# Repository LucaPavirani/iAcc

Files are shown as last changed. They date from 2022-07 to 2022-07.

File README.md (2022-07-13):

# Electronic Technologies and Biosensors Laboratory

## Academic Year 2021/2022 - II Semester

## Final Project - Project 4 - Respiratory/Heart Rate Monitor

## Objective

In this project, the aim was to develop a simple **Respiratory/Heart Rate Monitor** based on the PSoC and a 3-axis accelerometer LIS3DH. The device implements an algorithm for respiratory and heart rate computation, and then it allows data visualization on a custom GUI. PSOC and PC communication relies on a HC-05 BT Module either to make the device wearable and to reduce the cable bulkyness.
The PSoC communicates with the LIS3DH thanks to I2C communication, to acquire data at the best full-scale range possible, which has been set to $\pm 2G$, and with sampling frequency of 50 Hz.  
Finally, the whole PCB is powered thanks to a 9V battery, which allows the device to be portable and light. 

In the following image, the device is shown: 

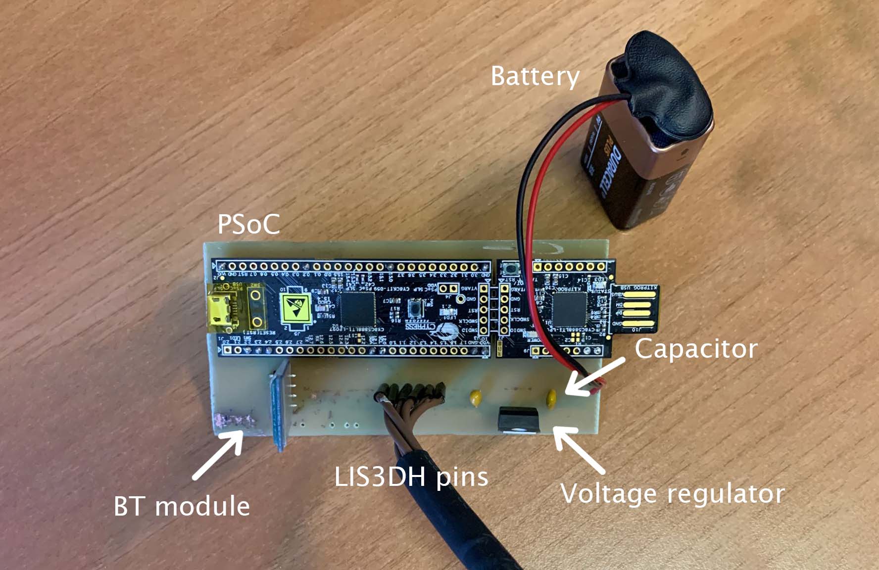
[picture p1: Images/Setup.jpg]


## Repository structure

### Design files

This folder contains all the projects used to model and 3D print the case and the chest mount for the sensor, along with the Eagle files, used to design the PCB. 

### Documentation

This folder contains the literature analysed during the development of the project, while the *Datasheets* folder contains all the datasheets for the components with some other useful files. 

### GUI

The GUI folder contains all the files necessary to run the graphical interface, which is the following:

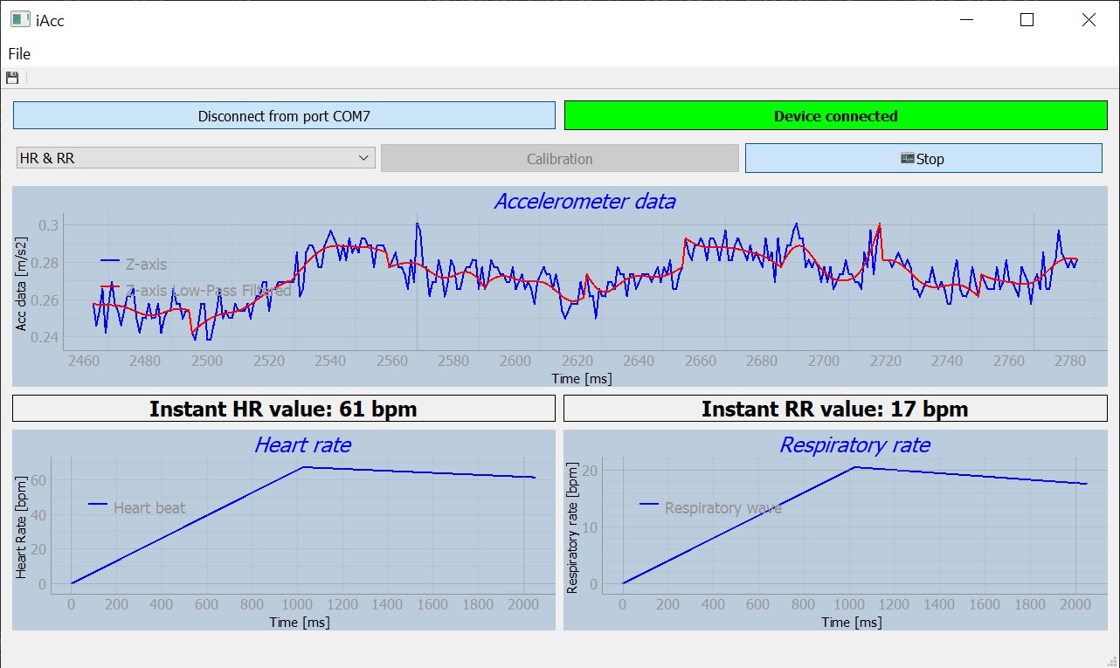
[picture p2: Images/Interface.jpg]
interface


The *device search* button enables the automatic scan of all the serial ports, looking for the device. As soon as it finds it, the connection is established and the box on the right becomes green, confirming the operation. The *combobox* allows to choose to read both HR and RR or only one of them. Calibration must be performed the first time that the device is worn, so that the algorithm computes the proper threshold to detect the rates. Once calibration is over (1 min approx.), the algorithm starts to accumulate data and to calculate the peaks from the signal, in order to compute RR and HR.

The *file* button allows to export the data in a `.csv` file. This operation will be automatically performed if the device is suddenly disconnected, so that the data is not lost. 

Heart Rate and Respiratory Rate are computed on non overlapping recording windows of 30s. Raw data are filtered and analysed in two different way for the computation of the rates. 

### Heart Rate computation

First, the absolute value of recorded data is filtered by a butter bandpass filter of the 4th order with frequency range in [1 ,5]Hz. The resulting signal is then smoothed first by a Savitzky-Golay filter of the 3rd order with window length of 15 samples and then by a moving average. These steps provide a resulting waveform that crearly shows the heart beats while being quite robust against noise.  
The next step provides the threshold as the 80% of the average of the data. The algorithm looks for the peaks above the calculated threshold that are at least 25 samples apart, that correspond to 0.5s approx.  
Finally, the Heart Rate is computed as the fraction between the number of peaks in the recorded window and the length of the window in seconds. This value is updated every 30s approx.

### Respiratory Rate computation

The computation of the Respiratory Rate requires different filtering of the signal.  
First, recorded data go through a butter lowpass filter of the 5th orded with cutoff frequency of 3Hz. This filtered signal is then smoothed by a Savitzky-Golay filter with a window of 31 samples and 3rd order. The threshold is calculated in the same way as in the HR computation, but the peaks are searched every 50 samples. 
The Respiratory Rate is calculated in the same way as the Heart Rate.

### Images

Images used for this `readme` file.

### PSoC

The *PSoC Code* folder contains all the files used to program the PSoC: in particular, all the functions and variables have been reordered in the proper file, allowing to increase the main.c file readibility.  
This code basically sets the proper configuration for the accelerometer registers at startup, making it ready for the data acquisition. All the different phases are managed thanks to a UART, that enables the different operations, according to the signals that come from the GUI. So, at the beginning the accelerometer is set and ready, once the PSoC receives the *start* signal from the GUI it begins to acquire data and to transmit them.  

Regarding the data acquisition, as previously mentioned the accelerometer has been set to a sampling frequency of 50 Hz, according to the Shannon's theorem and to the literature. In addition to that, the accelerometer operates in **FIFO mode**, so it accumulates all the samplings in the FIFO register (which contains up to 32 samples) and then it stops getting new data until the register has been emptied, allowing to reduce the computational load on the CPU and so the battery consumption, with respect to **bypass** mode, that sends the data in a continuous stream.  
In order to read the FIFO register, the PSoC checks regularly the value of the *overrun bit*, that becomes 1 once the FIFO register is full and returns to 0 when it has been entirely read.  
Once the `ovrn bit` changes to one, the register is entirely read, storing the data in the respective axis array. Then, the data is packed in one single array and sent via UART.

*Further implementation details can be found in each file.*

## Complete hardware list

- 1 PSoC CY8CKIT-059 
- 1 LIS3DH accelerometer
- 1 HC05 Bluetooth module
- 1 9V battery
- 1 9V to 5V voltage regulator 
- 6 cables for the accelerometer-PSoC communication

## How to wear the device

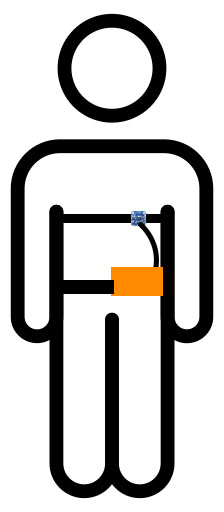
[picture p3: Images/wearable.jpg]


The 3D files for the case and the support can be found in the Design folder.

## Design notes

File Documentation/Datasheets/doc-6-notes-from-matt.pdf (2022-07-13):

# Porting the Arduino Library to the Cypress PSoC in PSoC Creator

Matt Durak

November 11, 2011

Design Team 1

### Abstract

Arduino, the open-source electronic platform is a useful tool to hobbyists in building embedded systems. It provides an easy to use library which includes components to work with an Ethernet board, called the Ethernet shield. PSoC is a programmable system-on-chip made by Cypress Semiconductor. It is a very flexible platform which includes an ARM Cortex M3 processor. This application note includes the steps necessary to port parts of the Arduino library to the PSoC in order to use Arduino software and hardware, known as shields, with the PSoC. The note will cover many issues which must be overcome in porting this software.

### Keywords

PSoC, Arduino, C++, C, Library, Software, Porting, PSoC Creator, Ethernet shield

### Introduction

### Arduino Library

The Arduino is an open-source electronics hardware platform that is designed primarily for students and hobbyists (1). Arduino provides the schematics to build the hardware, as well as kits which can be pre-assembled or just include the parts. This application note will focus on the software for Arduino. Arduino has its own open-source development environment based on Wiring, a platform for programming electronics (2). The software library used by Arduino is written in C++ and is also open-source and freely available (3).

This library is composed of a low layer which communicates directly with hardware registers and provides an abstraction for programmers to set whether a pin is an input or an output and to read and write to those pins. This low layer also handles the other hardware components on the Arduino, such as memory access, timers, pulse width modulators, and several forms of communication. The library also provides higher-level abstractions on top of this in order to make development easier.

The library contains sub-libraries for several Arduino daughterboards, which are called shields. This note will focus on the Ethernet shield as an example, although the note should be applicable to most components of the library. The Ethernet library itself also has a layer which defines the low level registers to communicate with over serial peripheral interface (SPI), as well as high level abstractions which make application code easier to write (4). The Ethernet library uses a separate SPI library component to handle the communication. This library provides an abstract interface to transmit bytes of data. It wraps the actual low level hardware communication in its implementation.

### PSoC Development

The Cypress Programmable System-on-Chip (PSoC), is a configurable piece of hardware which contains a number of programmable virtual components in order to implement a wide range of hardware features. This application note will focus on the PSoC 5, the latest family of PSoC. This version of the board contains an ARM Cortex M3 processor (5).

The development environment used by the PSoC is called PSoC Creator. This software is a full development environment for the PSoC. It contains a schematic layout tool in order to configure the programmable virtual hardware components. It also has a full C language IDE for developing code to run on the PSoC processor (6). This application note will focus on the programming side of PSoC Creator.

### Objective

The objective of this application note is to provide the steps necessary to take the Arduino software libraries, and compile them for the PSoC. This would allow a developer using a PSoC to run Arduino code and to possibly interface with an Arduino shield. The objective is not to show how to actually interface the PSoC hardware with an Arduino shield or to use the schematic layout tool in PSoC Creator. This application note assumes that the reader has acquired the latest development version of Arduino, found on Github (7).

### Issues

There are several issues to be aware of when porting code from one platform to another. The primary concerns in this case are the programming language, the standard libraries used by the code, and the implementation of the low-level details.

The issue with the programming language is mostly an minor incompatibility when using PSoC Creator. The Arduino libraries are primarily written in C++, although a few files are written in C. The PSoC Creator environment only officially supports C. However, PSoC Creator ships with the complete GNU Compiler Collection (GCC), which includes compilers for both C and C++. With a few minor modifications, PSoC Creator can compile C++ code. Another issue is the use of C++ in an embedded environment with very limited memory. C++ uses many advanced features such as polymorphism and virtual methods, templates, and run time type information which can add code bloat if used improperly (8). Fortunately, the standard Arduino board has a flash memory size of 32 KB, which is the same as the simplest PSoC 5 board. This means that the Arduino library has already been optimized to work with a similar memory constraint.

The next issue with the Arduino library code, is that the development library used by Arduino for its AVR ATMega processor uses standard AVR libraries with GCC. The PSoC uses the same version of GCC for embedded development; however it does not contain the AVR library used by Arduino. This requires some modification of the code to use the standard libraries available to PSoC.

Finally, the primary issue which will be addressed in this application note lies in the actual hardware implementations and low-level details of the Arduino library. This part of the code is very specific to the Arduino platform. The implementations will need to be re-written in order to make the library work on the PSoC platform.

### Steps

### Importing Arduino Sources

The process of porting the Arduino code begins with creating a new project in PSoC Creator. Next, it is necessary to create the digital and analog pins as well as any hardware components such as SPI and UART which will be used by the Arduino code. That process should be completed separately. The remaining steps assume that the PSoC Creator project contains a project with the schematic components necessary to emulate an Arduino board.

First, the following sources from the Arduino folder /hardware/cores/arduino/ must be added to the project: Arduino.h, Client.h, IPAddress.cpp, IPAddress.h, Print.cpp, Print.h, Printable.h, Server.h, Stream.cpp, Stream.h, Udp.h, WMath.cpp, binary.h, and new.cpp. It is recommended to add these to a new folder within the PSoC project in order to keep them separated from application code. Next, all files within the directory /libraries/Ethernet/, /libraries/Ethernet/utility/, and /libraries/SPI/ must be added to the project.

At this point, the project will probably build. This is because PSoC Creator does not compile files ending with the “.cpp” file extension. Fixing this requires manually modifying the “.cyprj” file. Open this file and find every “.cpp” file with a line like the following in Figure 1 and change the build action from “NONE” to “C_FILE” as in Figure 2. After repeating this for every C++ source file, save the file and PSoC Creator should reload the file. At this point, the files will all be built, but the compilation will fail.

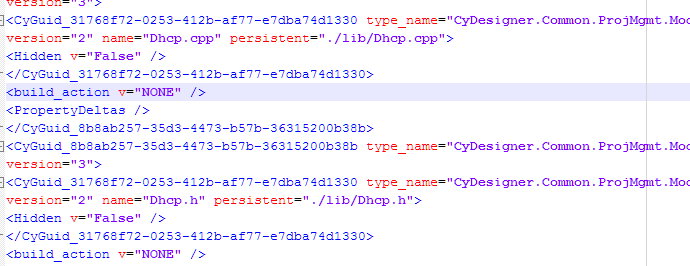
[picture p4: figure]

Figure 1 Project file before modification

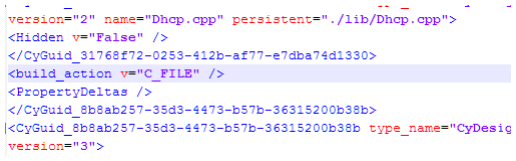
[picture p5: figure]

Figure 2 Project file after modification

### Fixes to get C++ Working

Now that C++ files can be built by PSoC Creator, some changes need to be made to get the project to compile. The first change is to modify the build settings of the project under the “Compiler” section and “Command Line” subsection. That command should include “-I./lib” where “lib” is the folder name where the Arduino sources are located. The command must also include “-fno-rtti” in order to disable run time type information in C++. These two command switches must both be added to make the library work.

Some of the other idiosyncrasies with using C++ are handled nicely by the Arduino library. Take a look at the file New.cpp to see some of the implementation used in order to get C++ working on an embedded system (9). This file is required to get the library to compile and link in PSoC Creator.

At this point, the remaining issues are due to including files that do not exist, using Arduino implementations, and some misnamed functions. However, one final item to note is that when working with C++ and including a C header, it is important to include the code in Listing 1 below. Without the ‘extern “C”’, the code will compile, but it will not link due to C++ name mangling (10). It is important to include this section of code whenever C header files are needed.

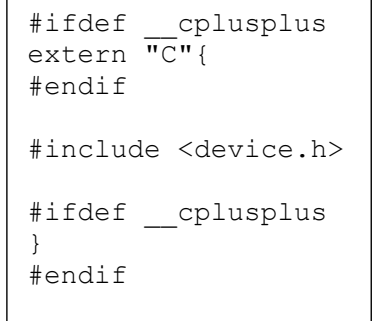
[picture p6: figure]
#ifdef __cplusplus extern "C"{ #endif; #include <device.h>; #ifdef __cplusplus } #endif

Listing 1 Including C headers in C++

### Getting the Library to Compile

The first step to getting the library to compile is to trim out any missing headers and to remove any Arduino specific implementations. The project already only includes a small subset of the entire library, but this next step will polish those sources to get them to work.

All files should have any reference to “AVR” includes removed (Listing 2). This is the standard library used by the AVR ATMega and it is not available for PSoC. The Arduino.h file has these include statements which should be removed. Likewise, any conditional statements using AVR, such as that in Listing 3, should be removed so that only the “else” portion remains.

The following functions in Arduino.h should be removed: init, pinMode, digitalWrite, digitalRead, analogRead, analogReference, analogWrite, micros, delay, delayMicroseconds, pulseIn, shiftOut, shiftIn, attachInterrupt, detachInterrupt, setup, loop, makeWord, tone, and noTone. The functions marked extern should also be removed. The “defines” starting at analogInPinToBit and continuing through TIMER5C should all be removed. Finally, the “includes” for WCharacter.h, WString.h, HardwareSerial.h, and pins_arduino.h should be removed. Within the extern “C” section, an “include” to CyLib.h must be added. This will provide useful functions which were removed from Arduino.h The final source code is included in the appendix.

Listing 2 Example AVR includes to remove

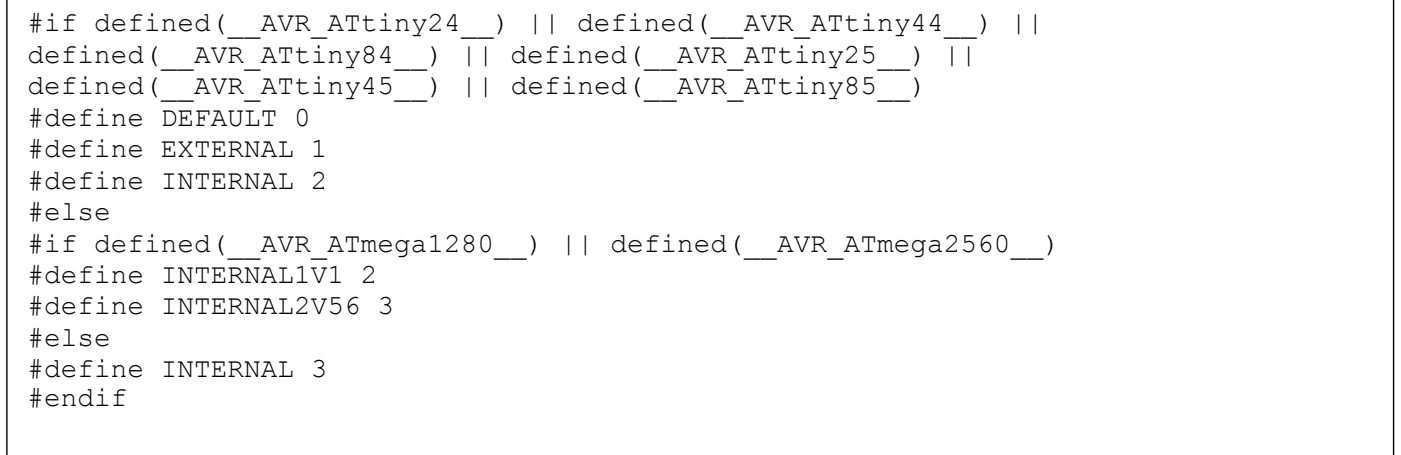
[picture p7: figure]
#define DEFAULT 0 #define EXTERNAL 1 #define INTERNAL 2 #else; #define INTERNAL1V1 2 #define INTERNAL2V56 3 #else #define INTERNAL 3 #endif

Listing 3 Example AVR conditional statements

The next file to modify is Print.h and Print.cpp. Each of these files must be modified to remove the “includes” to WString.h and instead include string.h. All methods that take a “String” or a “__FlashStringHelper” should be removed (Listing 4). These are simply function overloads and it is much easier to not include WString.h. The classes will still work with char* arrays.

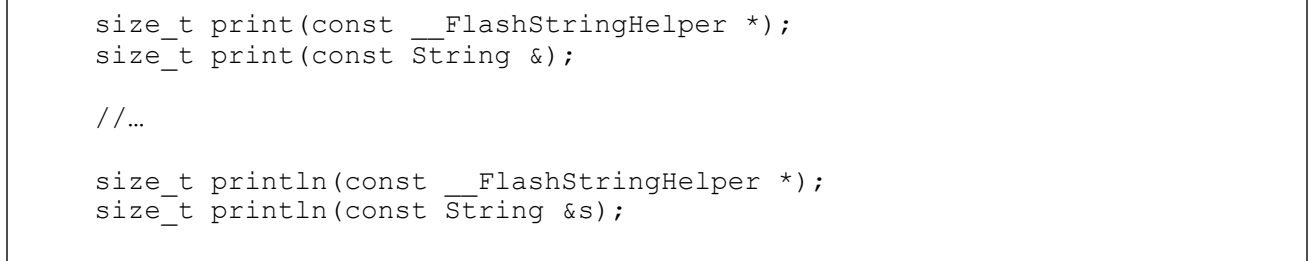
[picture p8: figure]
size_t print(const String &);; size_t println(const String &s);

Listing 4 Functions to remove

The next file to modify is WMath.cpp. This file must have an “include” to Arduino.h added. It must also change “srandom” and “random” to the standard “srand” and “rand” function calls. Finally, this is a good place to implement the “millis()” function. This function is used in Arduino to report the number of milliseconds which have elapsed since the device was powered on. It can be implemented using a counter in PSoC, but that is left to the reader to implement. This finishes the main parts of the Arduino library; next the Ethernet library must be fixed.

One change to make throughout several files here and any others added later, is to change all occurrences of “delay()” to “CyDelay()”. This will be a simple find and replace operation, as the “delay()” function is declared in Arduino.h and now Arduino.h includes CyLib.h which declares “CyDelay()”. This must be fixed in Dhcp.cpp, EthernetClient.cpp, Dns.cpp, and w5100.h.

It should be noted that there are two util.h files. These files should be merged from the main one in hardware to include the one found in the Ethernet library. The Ethernet library version of util.h defines the functions htonl, htons, ntohl, and ntohs in order to convert numbers from host to network endians

#if defined(__AVR_ATtiny24__) || defined(__AVR_ATtiny44__) || defined(__AVR_ATtiny84__) || defined(__AVR_ATtiny25__) || defined(__AVR_ATtiny45__) || defined(__AVR_ATtiny85__)

#if defined(__AVR_ATmega1280__) || defined(__AVR_ATmega2560__)

size_t print(const __FlashStringHelper *);

size_t println(const __FlashStringHelper *);

(which define the order of the bits in a number (11)). The merged version of util.h can be found in the appendix.

The final part of the Ethernet library to fix is the w5100.cpp and w5100.h. The w5100.h file must remove references to the avr headers and add includes to cytypes.h, util.h, and the digital pin used for the Ethernet slave select. The methods initSS, setSS, and resetSS must be changed in order to properly set the SPI slave select pin on the PSoC. The new implementation will not need to initialize the slave select, but it will need to write a “0” to the pin in setSS and write a “1” in resetSS. This code is shown in Listing 5 below. The w5100.cpp file must change delay to “CyDelay” as well as include CyLib.h for this function. There is also a required change in the function “void W5100Class::read_data(SOCKET s, volatile uint8_t *src, volatile uint8_t *dst, uint16_t len)”. There is a compiler error, but the changed code in Listing 6 below will fix this.

Listing 5 The slave select code

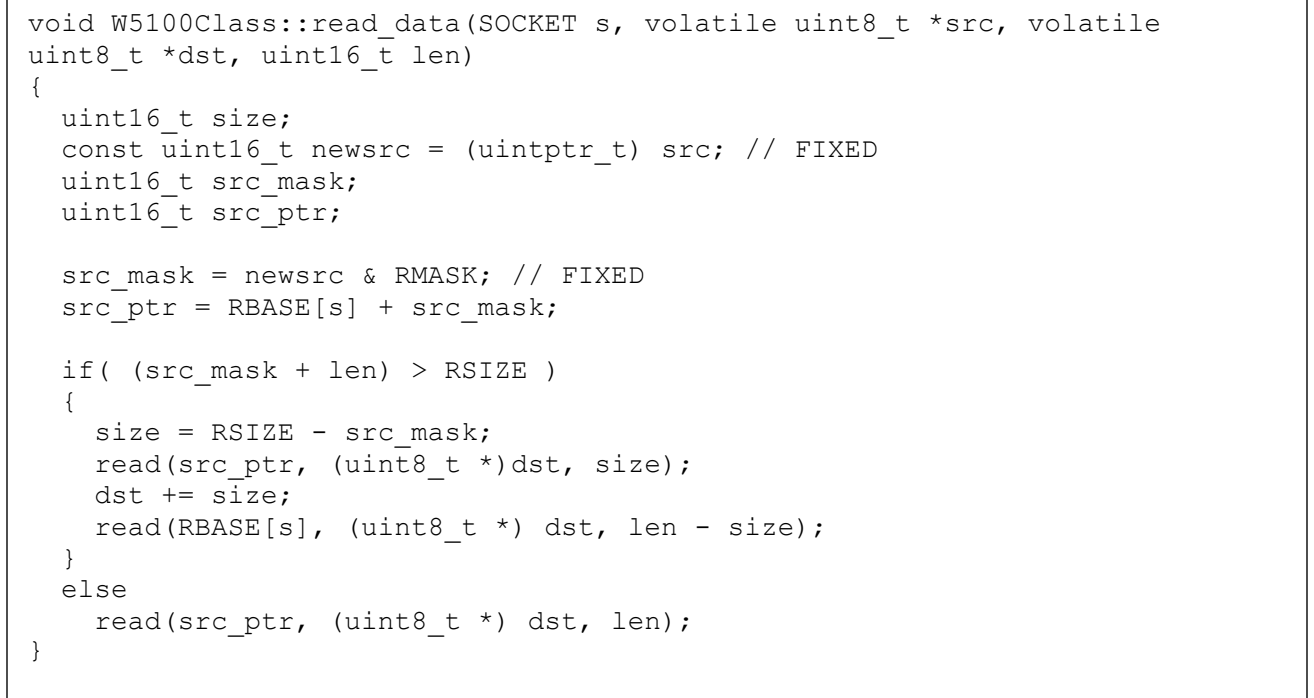
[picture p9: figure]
uint8_t *dst, uint16_t len) {; uint16_t size;; uint16_t src_mask; uint16_t src_ptr;; src_mask = newsrc & RMASK; // FIXED; src_ptr = RBASE[s] + src_mask;; if( (src_mask + len) > RSIZE ) {; size = RSIZE - src_mask; read(src_ptr, (uint8_t *)dst, size); dst += size;; } else read(src_ptr, (uint8_t *) dst, len);

Listing 6 Fixing a compiler error

The final library component to fix is the SPI. The file SPI.cpp requires major changes to the implementation. First the “include” to pins_arduino.h is removed. Next, all function implementation bodies may be removed. The only useful methods are “begin” and “end”. The body for begin should simply call “SPIM_1_Start();” and the body for end should call “SPIM_1_Stop();”. The other functions are configurations of SPI that must be made in the schematic layout mode. They are not necessary for the

inline static void setSS() | { D10_Write(0); /*PORTB &= ~_BV(2);*/ };
inline static void resetSS() | { D10_Write(1); /*PORTB |= | _BV(2);*/ };

void W5100Class::read_data(SOCKET s, volatile uint8_t *src, volatile

const uint16_t newsrc = (uintptr_t) src; // FIXED

read(RBASE[s], (uint8_t *) dst, len - size);

Ethernet library. The file SPI.h must remove the “include” to the avr header and add an “include” to the automatically generated SPI master header (SPIM_1.h by default). In this file, the bodies of attachInterrupt and detachInterrupt can be commented out temporarily. They are not used in the Ethernet code and can be implemented at a later point when they are needed. The most important function is transfer. This function handles actual SPI communication. The body of the function should be replaced with that in Listing 7. This uses the PSoC implementation of SPI. This is the final and most important implementation change to make.

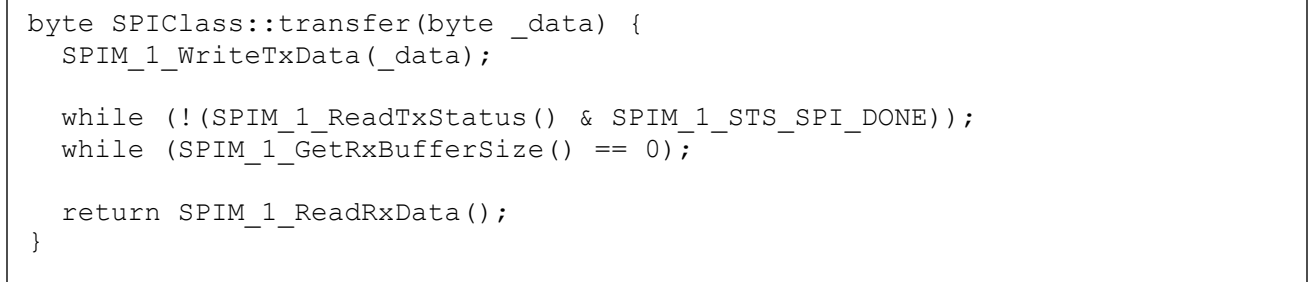
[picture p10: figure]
byte SPIClass::transfer(byte _data) { SPIM_1_WriteTxData(_data);; while (SPIM_1_GetRxBufferSize() == 0);; return SPIM_1_ReadRxData();

Listing 7 The SPI transfer method

### Results

After following the steps of the application note, and creating the proper virtual components in the schematic layout tool, the Arduino library can be built and programmed onto the PSoC. This is a subset of the library including the base components and the Ethernet and SPI libraries. Code that worked on Arduino can be copied into PSoC Creator and compiled to run on the PSoC with very minor modification. After building the hardware to connect the PSoC to an Arduino Ethernet shield, the Arduino Ethernet demos can be run on the PSoC with minor modification.

### Conclusions

Porting code from one embedded system to another can be a challenging task. There are many small implementation details which need to be considered. Likewise, it can be tricky to get C++ code working in an embedded environment which expects C code. However, the end result of this port which leaves the abstract interface intact is that code from one platform can be ported to the other platform for free. Porting the library is an investment which will make future work much easier.

### References

1. Arduino Team. Arduino - Homepage. Arduino. [Online] September 24, 2011. [Cited: November 9, 2011.] http://www.arduino.cc/.
2. Wiring. About Wiring. Wiring. [Online] November 9, 2011. [Cited: November 9, 2011.] http://wiring.org.co/about.html.

while (!(SPIM_1_ReadTxStatus() & SPIM_1_STS_SPI_DONE));

3. Mellis, David A. Introduction. Arduino. [Online] December 23, 2009. [Cited: November 9, 2011.] http://arduino.cc/en/Guide/Introduction.
4. —. Arduino. Ethernet. [Online] February 10, 2009. [Cited: November 9, 2011.] http://arduino.cc/en/Reference/Ethernet.
5. Cypress Semiconductor. PSoC 5 Introduction. Cypress. [Online] November 9, 2011. [Cited: November 9, 2011.] http://www.cypress.com/?id=2233&rID=37591.
6. —. PSoC Creator Overview. Cypress. [Online] November 9, 2011. [Cited: November 9, 2011.] http://www.cypress.com/?id=2494.
7. Arduino. Arduino. Github. [Online] November 9, 2011. [Cited: November 9, 2011.] https://github.com/arduino/Arduino.
8. Neundorf, Alexander. C vs. C++ for embedded development. KDE Blog. [Online] June 7, 2005. [Cited: November 9, 2011.] http://blogs.kde.org/node/1138.
9. Zed, Rob. GCC C++ Link problems on small embedded target. Zedcode. [Online] February 17, 2007. [Cited: November 9, 2011.] http://zedcode.blogspot.com/2007/02/gcc-c-link-problems-on-small-embedded.html.
10. Cline, Marshall. Why is the linker giving errors for C/C++ functions being called from C++/C functions? C++ FAQ Lite. [Online] July 28, 2011. [Cited: November 9, 2011.] http://www.parashift.com/c++-faq-lite/mixing-c-and-cpp.html#faq-32.7.
11. Hall, Brian. Beej's Guide to Network Programming. Beej.us. [Online] September 8, 2009. [Cited: November 9, 2011.] http://beej.us/guide/bgnet/output/html/multipage/htonsman.html.

### Appendix

### Arduino.h

#ifndef Arduino_h

#define Arduino_h

#include <stdlib.h>

#include <string.h>

#include <math.h>

#include "binary.h"

#ifdef __cplusplus

extern "C"{
#endif

#include <CyLib.h>

#define HIGH 0x1

#define LOW 0x0

#define INPUT 0x0

#define OUTPUT 0x1

#define true 0x1

#define false 0x0

#define PI 3.1415926535897932384626433832795

#define HALF_PI 1.5707963267948966192313216916398 #define TWO_PI 6.283185307179586476925286766559 #define DEG_TO_RAD 0.017453292519943295769236907684886 #define RAD_TO_DEG 57.295779513082320876798154814105

#define SERIAL 0x0

#define DISPLAY 0x1

#define LSBFIRST 0

#define MSBFIRST 1

#define CHANGE 1

#define FALLING 2

#define RISING 3

#define INTERNAL 3

#define DEFAULT 1

#define EXTERNAL 0

// undefine stdlib's abs if encountered #ifdef abs
#undef abs

#endif

#define min(a,b) ((a)<(b)?(a):(b)) #define max(a,b) ((a)>(b)?(a):(b))

#define abs(x) ((x)>0?(x):-(x))

#define constrain(amt,low,high) ((amt)<(low)?(low):((amt)>(high)?(high):(amt)))

#define round(x) | ((x)>=0?(long)((x)+0.5):(long)((x)-0.5))

#define radians(deg) ((deg)*DEG_TO_RAD)

#define degrees(rad) ((rad)*RAD_TO_DEG)

#define sq(x) ((x)*(x))

#define interrupts() sei()

#define noInterrupts() cli()

#define clockCyclesPerMicrosecond() ( F_CPU / 1000000L )

#define clockCyclesToMicroseconds(a) ( ((a) * 1000L) / (F_CPU / 1000L) ) #define microsecondsToClockCycles(a) ( ((a) * (F_CPU / 1000L)) / 1000L )

#define lowByte(w) ((uint8_t) ((w) & 0xff))

#define highByte(w) ((uint8_t) ((w) >> 8))

#define bitRead(value, bit) (((value) >> (bit)) & 0x01)

#define bitSet(value, bit) ((value) |= (1UL << (bit)))

#define bitClear(value, bit) ((value) &= ~(1UL << (bit)))

#define bitWrite(value, bit, bitvalue) (bitvalue ? bitSet(value, bit) : bitClear(value, bit))

typedef unsigned int word;

#define bit(b) (1UL << (b))

typedef uint8_t boolean;
typedef uint8_t byte;

unsigned long millis(void);

#ifdef __cplusplus

} // extern "C"
#endif

#ifdef __cplusplus

// WMath prototypes
long random(long);
long random(long, long);
void randomSeed(unsigned int);
long map(long, long, long, long, long);

#endif

#endif

### Util.h

#ifndef UTIL_INCLUDED

#define UTIL_INCLUDED

#define _BV(bit) (1 << (bit))

#ifdef __cplusplus

extern "C"{
#endif

#include <CyLib.h>

#ifdef __cplusplus

}
#endif

#define htons(x) CYSWAP_ENDIAN16(x) #define ntohs(x) htons(x)

#define htonl(x) CYSWAP_ENDIAN32(x) #define ntohl(x) htonl(x)

#endif

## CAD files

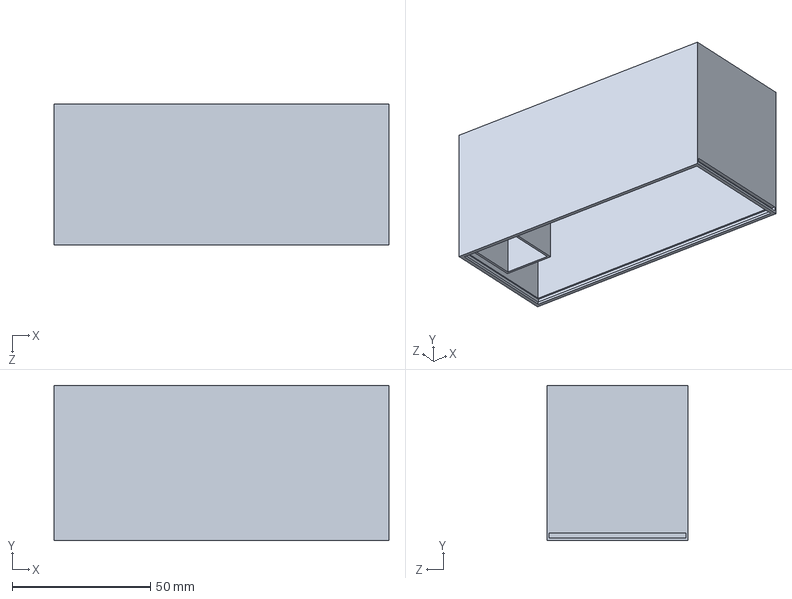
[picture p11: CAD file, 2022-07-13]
Design files/3D printer/case.SLDPRT
121.0 x 56.0 x 51.0 mm

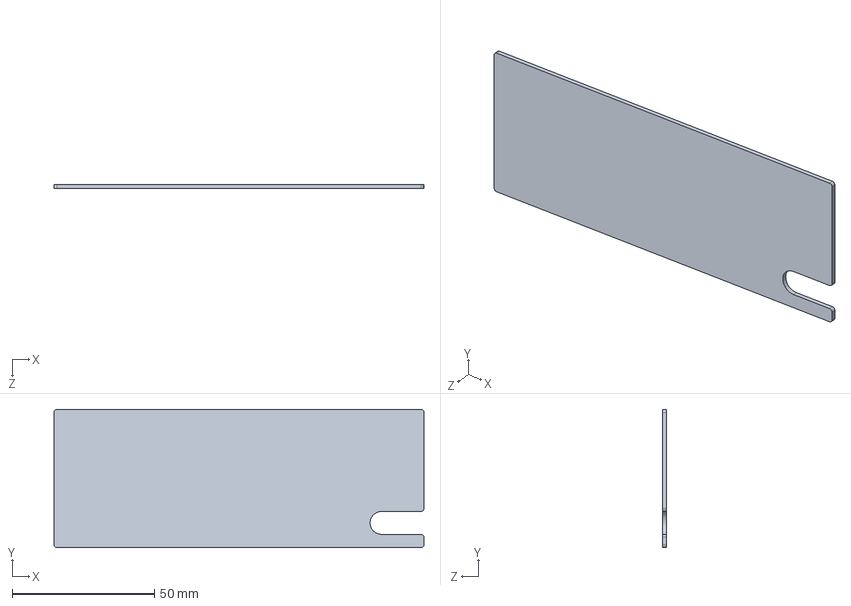
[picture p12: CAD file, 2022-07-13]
Design files/3D printer/supportLid.SLDPRT
130.0 x 48.5 x 1.45 mm

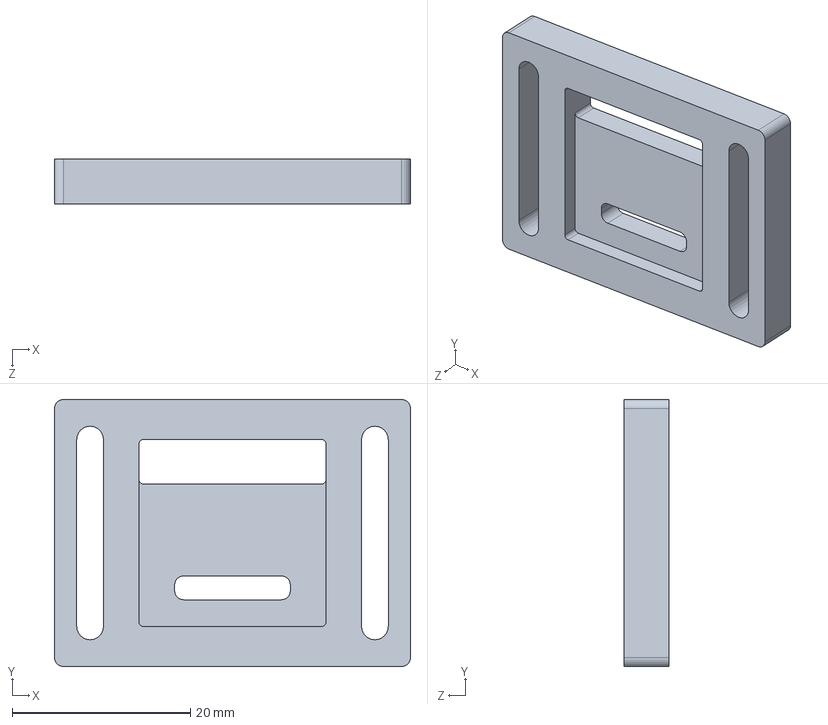
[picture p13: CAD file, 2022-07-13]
Design files/3D printer/accelerometerSupport.SLDPRT
40.0 x 30.0 x 5.00 mm

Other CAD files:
Design files/3D printer/accelerometerSupport.STL
Design files/3D printer/case.STL
Design files/3D printer/supportLid.STL

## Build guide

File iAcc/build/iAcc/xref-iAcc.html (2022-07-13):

# modulegraph cross reference for iAcc.py, pyi_rth_inspect.py, pyi_rth_mplconfig.py, pyi_rth_multiprocessing.py, pyi_rth_pkgres.py, pyi_rth_pkgutil.py, pyi_rth_pyqt5.py, pyi_rth_subprocess.py

iAcc.py Script

imports: PyQt5 • PyQt5.QtCore • PyQt5.QtGui • PyQt5.QtWidgets • _bootlocale • _collections_abc • _weakrefset • abc • codecs • collections • collections.abc • copyreg • encodings • encodings.aliases • encodings.ascii • encodings.base64_codec • encodings.big5 • encodings.big5hkscs • encodings.bz2_codec • encodings.charmap • encodings.cp037 • encodings.cp1006 • encodings.cp1026 • encodings.cp1125 • encodings.cp1140 • encodings.cp1250 • encodings.cp1251 • encodings.cp1252 • encodings.cp1253 • encodings.cp1254 • encodings.cp1255 • encodings.cp1256 • encodings.cp1257 • encodings.cp1258 • encodings.cp273 • encodings.cp424 • encodings.cp437 • encodings.cp500 • encodings.cp65001 • encodings.cp720 • encodings.cp737 • encodings.cp775 • encodings.cp850 • encodings.cp852 • encodings.cp855 • encodings.cp856 • encodings.cp857 • encodings.cp858 • encodings.cp860 • encodings.cp861 • encodings.cp862 • encodings.cp863 • encodings.cp864 • encodings.cp865 • encodings.cp866 • encodings.cp869 • encodings.cp874 • encodings.cp875 • encodings.cp932 • encodings.cp949 • encodings.cp950 • encodings.euc_jis_2004 • encodings.euc_jisx0213 • encodings.euc_jp • encodings.euc_kr • encodings.gb18030 • encodings.gb2312 • encodings.gbk • encodings.hex_codec • encodings.hp_roman8 • encodings.hz • encodings.idna • encodings.iso2022_jp • encodings.iso2022_jp_1 • encodings.iso2022_jp_2 • encodings.iso2022_jp_2004 • encodings.iso2022_jp_3 • encodings.iso2022_jp_ext • encodings.iso2022_kr • encodings.iso8859_1 • encodings.iso8859_10 • encodings.iso8859_11 • encodings.iso8859_13 • encodings.iso8859_14 • encodings.iso8859_15 • encodings.iso8859_16 • encodings.iso8859_2 • encodings.iso8859_3 • encodings.iso8859_4 • encodings.iso8859_5 • encodings.iso8859_6 • encodings.iso8859_7 • encodings.iso8859_8 • encodings.iso8859_9 • encodings.johab • encodings.koi8_r • encodings.koi8_t • encodings.koi8_u • encodings.kz1048 • encodings.latin_1 • encodings.mac_arabic • encodings.mac_centeuro • encodings.mac_croatian • encodings.mac_cyrillic • encodings.mac_farsi • encodings.mac_greek • encodings.mac_iceland • encodings.mac_latin2 • encodings.mac_roman • encodings.mac_romanian • encodings.mac_turkish • encodings.mbcs • encodings.oem • encodings.palmos • encodings.ptcp154 • encodings.punycode • encodings.quopri_codec • encodings.raw_unicode_escape • encodings.rot_13 • encodings.shift_jis • encodings.shift_jis_2004 • encodings.shift_jisx0213 • encodings.tis_620 • encodings.undefined • encodings.unicode_escape • encodings.unicode_internal • encodings.utf_16 • encodings.utf_16_be • encodings.utf_16_le • encodings.utf_32 • encodings.utf_32_be • encodings.utf_32_le • encodings.utf_7 • encodings.utf_8 • encodings.utf_8_sig • encodings.uu_codec • encodings.zlib_codec • enum • functools • heapq • io • keyword • linecache • locale • logging • matplotlib.pyplot • numpy • operator • pandas • pyi_rth_inspect.py • pyi_rth_mplconfig.py • pyi_rth_multiprocessing.py • pyi_rth_pkgres.py • pyi_rth_pkgutil.py • pyi_rth_pyqt5.py • pyi_rth_subprocess.py • pyqtgraph • re • reprlib • scipy.signal • serial • serial.tools.list_ports • setuptools • sre_compile • sre_constants • sre_parse • struct • sys • telnetlib • time • tokenize • traceback • types • variables • warnings • weakref

pyi_rth_inspect.py Script

imports: inspect • os • sys

imported by: iAcc.py

pyi_rth_mplconfig.py Script

imports: atexit • os • shutil • tempfile

imported by: iAcc.py

pyi_rth_multiprocessing.py Script

imports: multiprocessing • multiprocessing.popen_fork • multiprocessing.popen_spawn_posix • multiprocessing.popen_spawn_win32 • multiprocessing.spawn • os • subprocess • sys

imported by: iAcc.py

pyi_rth_pkgres.py Script

imports: os • pathlib • pkg_resources • pyimod03_importers • sys

imported by: iAcc.py

pyi_rth_pkgutil.py Script

imports: os • pkgutil • pyimod03_importers • sys

imported by: iAcc.py

pyi_rth_pyqt5.py Script

imports: os • sys

imported by: iAcc.py

pyi_rth_subprocess.py Script

imports: io • subprocess • sys

imported by: iAcc.py

'IPython.core' MissingModule

imported by: matplotlib.backend_bases • matplotlib.pyplot • pandas.io.formats.printing

'OpenGL.GL' MissingModule

imported by: pyqtgraph.widgets.RawImageWidget

'PyQt6.QtCore' MissingModule

imported by: pyqtgraph.Qt

'PyQt6.QtGui' MissingModule

imported by: PIL.ImageQt • pyqtgraph.Qt

'PyQt6.QtWidgets' MissingModule

imported by: pyqtgraph.Qt

'PySide2.QtCore' MissingModule

imported by: pyqtgraph.GraphicsScene.exportDialogTemplate_pyside2 • pyqtgraph.Qt • pyqtgraph.examples.VideoTemplate_pyside2 • pyqtgraph.examples.exampleLoaderTemplate_pyside2

'PySide2.QtGui' MissingModule

imported by: PIL.ImageQt • pyqtgraph.GraphicsScene.exportDialogTemplate_pyside2 • pyqtgraph.Qt • pyqtgraph.examples.VideoTemplate_pyside2 • pyqtgraph.examples.exampleLoaderTemplate_pyside2

'PySide2.QtWidgets' MissingModule

imported by: pyqtgraph.GraphicsScene.exportDialogTemplate_pyside2 • pyqtgraph.Qt • pyqtgraph.examples.VideoTemplate_pyside2 • pyqtgraph.examples.exampleLoaderTemplate_pyside2

'PySide6.QtCore' MissingModule

imported by: pyqtgraph.GraphicsScene.exportDialogTemplate_pyside6 • pyqtgraph.Qt • pyqtgraph.canvas.CanvasTemplate_pyside6 • pyqtgraph.canvas.TransformGuiTemplate_pyside6 • pyqtgraph.examples.VideoTemplate_pyside6 • pyqtgraph.examples.exampleLoaderTemplate_pyside6 • pyqtgraph.flowchart.FlowchartCtrlTemplate_pyside6 • pyqtgraph.flowchart.FlowchartTemplate_pyside6 • pyqtgraph.graphicsItems.PlotItem.plotConfigTemplate_pyside6 • pyqtgraph.graphicsItems.ViewBox.axisCtrlTemplate_pyside6 • pyqtgraph.imageview.ImageViewTemplate_pyside6

'PySide6.QtGui' MissingModule

imported by: PIL.ImageQt • pyqtgraph.GraphicsScene.exportDialogTemplate_pyside6 • pyqtgraph.Qt • pyqtgraph.canvas.CanvasTemplate_pyside6 • pyqtgraph.canvas.TransformGuiTemplate_pyside6 • pyqtgraph.examples.VideoTemplate_pyside6 • pyqtgraph.examples.exampleLoaderTemplate_pyside6 • pyqtgraph.flowchart.FlowchartCtrlTemplate_pyside6 • pyqtgraph.flowchart.FlowchartTemplate_pyside6 • pyqtgraph.graphicsItems.PlotItem.plotConfigTemplate_pyside6 • pyqtgraph.graphicsItems.ViewBox.axisCtrlTemplate_pyside6 • pyqtgraph.imageview.ImageViewTemplate_pyside6

'PySide6.QtWidgets' MissingModule

imported by: pyqtgraph.GraphicsScene.exportDialogTemplate_pyside6 • pyqtgraph.Qt • pyqtgraph.canvas.CanvasTemplate_pyside6 • pyqtgraph.canvas.TransformGuiTemplate_pyside6 • pyqtgraph.examples.VideoTemplate_pyside6 • pyqtgraph.examples.exampleLoaderTemplate_pyside6 • pyqtgraph.flowchart.FlowchartCtrlTemplate_pyside6 • pyqtgraph.flowchart.FlowchartTemplate_pyside6 • pyqtgraph.graphicsItems.PlotItem.plotConfigTemplate_pyside6 • pyqtgraph.graphicsItems.ViewBox.axisCtrlTemplate_pyside6 • pyqtgraph.imageview.ImageViewTemplate_pyside6

'System.IO' MissingModule

imported by: serial.serialcli

'backports.ssl_match_hostname' MissingModule

imported by: setuptools.ssl_support

'com.sun' MissingModule

imported by: pkg_resources._vendor.appdirs

'h5py.highlevel' MissingModule

imported by: pyqtgraph.metaarray.MetaArray

'java.lang' MissingModule

imported by: platform • xml.sax._exceptions

'lxml.etree' MissingModule

imported by: pandas.io.formats.xml • pandas.io.html • pandas.io.xml

'lxml.html' MissingModule

imported by: pandas.io.html

'nose.plugins' MissingModule

imported by: numpy.testing._private.noseclasses • numpy.testing._private.nosetester

'nose.util' MissingModule

imported by: numpy.testing._private.noseclasses

'odf.config' MissingModule

imported by: pandas.io.excel._odswriter

'odf.element' MissingModule

imported by: pandas.io.excel._odfreader

'odf.namespaces' MissingModule

imported by: pandas.io.excel._odfreader

'odf.opendocument' MissingModule

imported by: pandas.io.excel._odfreader • pandas.io.excel._odswriter

'odf.style' MissingModule

imported by: pandas.io.excel._odswriter

'odf.table' MissingModule

imported by: pandas.io.excel._odfreader • pandas.io.excel._odswriter

'odf.text' MissingModule

imported by: pandas.io.excel._odfreader • pandas.io.excel._odswriter

'openpyxl.cell' MissingModule

imported by: pandas.io.excel._openpyxl

'openpyxl.styles' MissingModule

imported by: pandas.io.excel._openpyxl

'openpyxl.workbook' MissingModule

imported by: pandas.io.excel._openpyxl

'org.python' MissingModule

imported by: pickle • setuptools.sandbox • xml.sax

'pkg_resources.extern.pyparsing' MissingModule

imported by: pkg_resources._vendor.packaging.markers • pkg_resources._vendor.packaging.requirements

'pkg_resources.extern.six.moves' MissingModule

imported by: pkg_resources • pkg_resources._vendor.packaging.requirements

'pyarrow.compute' MissingModule

imported by: pandas.core.arrays.string_arrow

'pyarrow.parquet' MissingModule

imported by: pandas.io.parquet

'scikits.umfpack' MissingModule

imported by: scipy.optimize._linprog_ip

'setuptools._vendor.six.moves' MissingModule

imported by: 'setuptools._vendor.six.moves'

'setuptools._vendor.six.moves' AliasNode

imports: 'setuptools._vendor.six.moves' • 'setuptools._vendor.six.moves'.parse • setuptools.extern.six.moves

imported by: setuptools._vendor.packaging.requirements • setuptools.extern.six.moves • setuptools.package_index • setuptools.ssl_support

'setuptools._vendor.six.moves'.parse MissingModule

imported by: 'setuptools._vendor.six.moves' • setuptools._vendor.packaging.requirements

'setuptools.extern.packaging' MissingModule

imported by: setuptools.wheel

'setuptools.extern.packaging.version' MissingModule

imported by: setuptools.config • setuptools.msvc

'setuptools.extern.pyparsing' MissingModule

imported by: setuptools._vendor.packaging.markers • setuptools._vendor.packaging.requirements

'setuptools.extern.six' MissingModule

imported by: setuptools

'sksparse.cholmod' MissingModule

imported by: scipy.optimize._linprog_ip

'sqlalchemy.schema' MissingModule

imported by: pandas.io.sql

'sqlalchemy.types' MissingModule

imported by: pandas.io.sql

'tornado.ioloop' MissingModule

imported by: matplotlib.backends.backend_webagg

'tornado.template' MissingModule

imported by: matplotlib.backends.backend_webagg

'tornado.web' MissingModule

imported by: matplotlib.backends.backend_webagg

'tornado.websocket' MissingModule

imported by: matplotlib.backends.backend_webagg

'win32com.shell' MissingModule

imported by: pkg_resources._vendor.appdirs

AppKit MissingModule

imported by: pandas.io.clipboard

CanvasManager MissingModule

imported by: pyqtgraph.canvas.CanvasTemplate_pyside2

Foundation MissingModule

imported by: pandas.io.clipboard

GraphicsView MissingModule

imported by: pyqtgraph.SRTTransform • pyqtgraph.SRTTransform3D

IPython MissingModule

imported by: matplotlib.backend_bases • matplotlib.pyplot • pandas.io.formats.printing

OpenGL MissingModule

imported by: pyqtgraph.graphicsItems.PlotCurveItem

PIL Package

imports: PIL • PIL.BmpImagePlugin • PIL.FitsImagePlugin • PIL.GifImagePlugin • PIL.GimpGradientFile • PIL.GimpPaletteFile • PIL.Image • PIL.ImageChops • PIL.ImageColor • PIL.ImageFile • PIL.ImageFilter • PIL.ImageMode • PIL.ImageOps • PIL.ImagePalette • PIL.ImageQt • PIL.ImageSequence • PIL.ImageShow • PIL.ImageTk • PIL.JpegImagePlugin • PIL.PaletteFile • PIL.PdfParser • PIL.PngImagePlugin • PIL.PpmImagePlugin • PIL.PyAccess • PIL.TiffImagePlugin • PIL.TiffTags • PIL._imaging • PIL._imagingtk • PIL._version • PIL._webp • PIL.features

imported by: PIL • PIL.BlpImagePlugin • PIL.BmpImagePlugin • PIL.BufrStubImagePlugin • PIL.CurImagePlugin • PIL.DcxImagePlugin • PIL.DdsImagePlugin • PIL.EpsImagePlugin • PIL.FitsImagePlugin • PIL.FitsStubImagePlugin • PIL.FliImagePlugin • PIL.FpxImagePlugin • PIL.FtexImagePlugin • PIL.GbrImagePlugin • PIL.GifImagePlugin • PIL.GimpGradientFile • PIL.GimpPaletteFile • PIL.GribStubImagePlugin • PIL.Hdf5StubImagePlugin • PIL.IcnsImagePlugin • PIL.IcoImagePlugin • PIL.ImImagePlugin • PIL.Image • PIL.ImageChops • PIL.ImageColor • PIL.ImageFile • PIL.ImageFilter • PIL.ImageMode • PIL.ImageOps • PIL.ImagePalette • PIL.ImageQt • PIL.ImageSequence • PIL.ImageShow • PIL.ImageTk • PIL.ImtImagePlugin • PIL.IptcImagePlugin • PIL.Jpeg2KImagePlugin • PIL.JpegImagePlugin • PIL.JpegPresets • PIL.McIdasImagePlugin • PIL.MicImagePlugin • PIL.MpegImagePlugin • PIL.MpoImagePlugin • PIL.MspImagePlugin • PIL.PaletteFile • PIL.PalmImagePlugin • PIL.PcdImagePlugin • PIL.PcxImagePlugin • PIL.PdfImagePlugin • PIL.PdfParser • PIL.PixarImagePlugin • PIL.PngImagePlugin • PIL.PpmImagePlugin • PIL.PsdImagePlugin • PIL.PyAccess • PIL.SgiImagePlugin • PIL.SpiderImagePlugin • PIL.SunImagePlugin • PIL.TgaImagePlugin • PIL.TiffImagePlugin • PIL.TiffTags • PIL.WebPImagePlugin • PIL.WmfImagePlugin • PIL.XVThumbImagePlugin • PIL.XbmImagePlugin • PIL.XpmImagePlugin • PIL._binary • PIL._imaging • PIL._imagingtk • PIL._util • PIL._version • PIL._webp • PIL.features • PyInstaller.building.icon • PyInstaller.building.splash • matplotlib.backends.backend_agg • matplotlib.backends.backend_webagg_core • matplotlib.colors • matplotlib.mathtext

PIL.BlpImagePlugin SourceModule

imports: PIL • PIL.Image • PIL.ImageFile • PIL.JpegImagePlugin • enum • io • os • struct • warnings

imported by: PIL.Image

PIL.BmpImagePlugin SourceModule

imports: PIL • PIL.Image • PIL.ImageFile • PIL.ImagePalette • PIL._binary • os

imported by: PIL • PIL.CurImagePlugin • PIL.IcoImagePlugin • PIL.Image

PIL.BufrStubImagePlugin SourceModule

imports: PIL • PIL.Image • PIL.ImageFile

imported by: PIL.Image

PIL.CurImagePlugin SourceModule

imports: PIL • PIL.BmpImagePlugin • PIL.Image • PIL._binary

imported by: PIL.Image

PIL.DcxImagePlugin SourceModule

imports: PIL • PIL.Image • PIL.PcxImagePlugin • PIL._binary

imported by: PIL.Image

PIL.DdsImagePlugin SourceModule

imports: PIL • PIL.Image • PIL.ImageFile • PIL._binary • io • struct

imported by: PIL.Image

PIL.EpsImagePlugin SourceModule

imports: PIL • PIL.Image • PIL.ImageFile • PIL._binary • io • os • re • shutil • subprocess • sys • tempfile

imported by: PIL.Image

PIL.FitsImagePlugin SourceModule

imports: PIL • PIL.Image • PIL.ImageFile • math

imported by: PIL • PIL.FitsStubImagePlugin • PIL.Image

PIL.FitsStubImagePlugin SourceModule

imports: PIL • PIL.FitsImagePlugin • PIL.Image • PIL.ImageFile • warnings

imported by: PIL.Image

PIL.FliImagePlugin SourceModule

imports: PIL • PIL.Image • PIL.ImageFile • PIL.ImagePalette • PIL._binary

imported by: PIL.Image

PIL.FpxImagePlugin SourceModule

imports: PIL • PIL.Image • PIL.ImageFile • PIL._binary • olefile

imported by: PIL.Image

PIL.FtexImagePlugin SourceModule

imports: PIL • PIL.Image • PIL.ImageFile • enum • io • struct • warnings

imported by: PIL.Image

PIL.GbrImagePlugin SourceModule

imports: PIL • PIL.Image • PIL.ImageFile • PIL._binary

imported by: PIL.Image

PIL.GifImagePlugin SourceModule

imports: PIL • PIL.Image • PIL.ImageChops • PIL.ImageFile • PIL.ImagePalette • PIL.ImageSequence • PIL._binary • copy • enum • itertools • math • os • subprocess

imported by: PIL • PIL.Image

PIL.GimpGradientFile SourceModule

imports: PIL • PIL._binary • math

imported by: PIL • PIL.ImagePalette

PIL.GimpPaletteFile SourceModule

imports: PIL • PIL._binary • re

imported by: PIL • PIL.ImagePalette

PIL.GribStubImagePlugin SourceModule

imports: PIL • PIL.Image • PIL.ImageFile

imported by: PIL.Image

PIL.Hdf5StubImagePlugin SourceModule

imports: PIL • PIL.Image • PIL.ImageFile

imported by: PIL.Image

PIL.IcnsImagePlugin SourceModule

imports: PIL • PIL.Image • PIL.ImageFile • PIL.Jpeg2KImagePlugin • PIL.PngImagePlugin • PIL.features • io • os • struct • sys

imported by: PIL.Image

PIL.IcoImagePlugin SourceModule

imports: PIL • PIL.BmpImagePlugin • PIL.Image • PIL.ImageFile • PIL.PngImagePlugin • PIL._binary • io • math • warnings

imported by: PIL.Image

PIL.ImImagePlugin SourceModule

imports: PIL • PIL.Image • PIL.ImageFile • PIL.ImagePalette • os • re

imported by: PIL.Image

PIL.Image SourceModule

imports: PIL • PIL.BlpImagePlugin • PIL.BmpImagePlugin • PIL.BufrStubImagePlugin • PIL.CurImagePlugin • PIL.DcxImagePlugin • PIL.DdsImagePlugin • PIL.EpsImagePlugin • PIL.FitsImagePlugin • PIL.FitsStubImagePlugin • PIL.FliImagePlugin • PIL.FpxImagePlugin • PIL.FtexImagePlugin • PIL.GbrImagePlugin • PIL.GifImagePlugin • PIL.GribStubImagePlugin • PIL.Hdf5StubImagePlugin • PIL.IcnsImagePlugin • PIL.IcoImagePlugin • PIL.ImImagePlugin • PIL.ImageColor • PIL.ImageFilter • PIL.ImageMode • PIL.ImagePalette • PIL.ImageQt • PIL.ImageShow • PIL.ImtImagePlugin • PIL.IptcImagePlugin • PIL.Jpeg2KImagePlugin • PIL.JpegImagePlugin • PIL.McIdasImagePlugin • PIL.MicImagePlugin • PIL.MpegImagePlugin • PIL.MpoImagePlugin • PIL.MspImagePlugin • PIL.PalmImagePlugin • PIL.PcdImagePlugin • PIL.PcxImagePlugin • PIL.PdfImagePlugin • PIL.PixarImagePlugin • PIL.PngImagePlugin • PIL.PpmImagePlugin • PIL.PsdImagePlugin • PIL.PyAccess • PIL.SgiImagePlugin • PIL.SpiderImagePlugin • PIL.SunImagePlugin • PIL.TgaImagePlugin • PIL.TiffImagePlugin • PIL.TiffTags • PIL.WebPImagePlugin • PIL.WmfImagePlugin • PIL.XVThumbImagePlugin • PIL.XbmImagePlugin • PIL.XpmImagePlugin • PIL._binary • PIL._imaging • PIL._util • atexit • builtins • cffi • collections.abc • defusedxml • enum • io • logging • math • numbers • numpy • os • pathlib • re • struct • sys • tempfile • warnings

imported by: PIL • PIL.BlpImagePlugin • PIL.BmpImagePlugin • PIL.BufrStubImagePlugin • PIL.CurImagePlugin • PIL.DcxImagePlugin • PIL.DdsImagePlugin • PIL.EpsImagePlugin • PIL.FitsImagePlugin • PIL.FitsStubImagePlugin • PIL.FliImagePlugin • PIL.FpxImagePlugin • PIL.FtexImagePlugin • PIL.GbrImagePlugin • PIL.GifImagePlugin • PIL.GribStubImagePlugin • PIL.Hdf5StubImagePlugin • PIL.IcnsImagePlugin • PIL.IcoImagePlugin • PIL.ImImagePlugin • PIL.ImageChops • PIL.ImageColor • PIL.ImageFile • PIL.ImageFilter • PIL.ImageOps • PIL.ImageQt • PIL.ImageShow • PIL.ImageTk • PIL.ImtImagePlugin • PIL.IptcImagePlugin • PIL.Jpeg2KImagePlugin • PIL.JpegImagePlugin • PIL.McIdasImagePlugin • PIL.MicImagePlugin • PIL.MpegImagePlugin • PIL.MpoImagePlugin • PIL.MspImagePlugin • PIL.PalmImagePlugin • PIL.PcdImagePlugin • PIL.PcxImagePlugin • PIL.PdfImagePlugin • PIL.PixarImagePlugin • PIL.PngImagePlugin • PIL.PpmImagePlugin • PIL.PsdImagePlugin • PIL.SgiImagePlugin • PIL.SpiderImagePlugin • PIL.SunImagePlugin • PIL.TgaImagePlugin • PIL.TiffImagePlugin • PIL.WebPImagePlugin • PIL.WmfImagePlugin • PIL.XVThumbImagePlugin • PIL.XbmImagePlugin • PIL.XpmImagePlugin • PIL.features • PyInstaller.building.icon • PyInstaller.building.splash • matplotlib.backends.backend_agg • matplotlib.backends.backend_webagg_core • matplotlib.colors • matplotlib.mathtext

PIL.ImageChops SourceModule

imports: PIL • PIL.Image

imported by: PIL • PIL.GifImagePlugin • PIL.PngImagePlugin

PIL.ImageColor SourceModule

imports: PIL • PIL.Image • colorsys • re

imported by: PIL • PIL.Image • PIL.ImageOps • PIL.ImagePalette

PIL.ImageFile SourceModule

imports: PIL • PIL.Image • PIL._util • io • itertools • mmap • struct • sys

imported by: PIL • PIL.BlpImagePlugin • PIL.BmpImagePlugin • PIL.BufrStubImagePlugin • PIL.DdsImagePlugin • PIL.EpsImagePlugin • PIL.FitsImagePlugin • PIL.FitsStubImagePlugin • PIL.FliImagePlugin • PIL.FpxImagePlugin • PIL.FtexImagePlugin • PIL.GbrImagePlugin • PIL.GifImagePlugin • PIL.GribStubImagePlugin • PIL.Hdf5StubImagePlugin • PIL.IcnsImagePlugin • PIL.IcoImagePlugin • PIL.ImImagePlugin • PIL.ImtImagePlugin • PIL.IptcImagePlugin • PIL.Jpeg2KImagePlugin • PIL.JpegImagePlugin • PIL.McIdasImagePlugin • PIL.MpegImagePlugin • PIL.MpoImagePlugin • PIL.MspImagePlugin • PIL.PalmImagePlugin • PIL.PcdImagePlugin • PIL.PcxImagePlugin • PIL.PdfImagePlugin • PIL.PixarImagePlugin • PIL.PngImagePlugin • PIL.PpmImagePlugin • PIL.PsdImagePlugin • PIL.SgiImagePlugin • PIL.SpiderImagePlugin • PIL.SunImagePlugin • PIL.TgaImagePlugin • PIL.TiffImagePlugin • PIL.WebPImagePlugin • PIL.WmfImagePlugin • PIL.XVThumbImagePlugin • PIL.XbmImagePlugin • PIL.XpmImagePlugin

PIL.ImageFilter SourceModule

imports: PIL • PIL.Image • functools

imported by: PIL • PIL.Image

PIL.ImageMode SourceModule

imports: PIL • sys

imported by: PIL • PIL.Image

PIL.ImageOps SourceModule

imports: PIL • PIL.Image • PIL.ImageColor • functools • operator • re

imported by: PIL • PIL.TiffImagePlugin

PIL.ImagePalette SourceModule

imports: PIL • PIL.GimpGradientFile • PIL.GimpPaletteFile • PIL.ImageColor • PIL.PaletteFile • array • random • warnings

imported by: PIL • PIL.BmpImagePlugin • PIL.FliImagePlugin • PIL.GifImagePlugin • PIL.ImImagePlugin • PIL.Image • PIL.PcxImagePlugin • PIL.PngImagePlugin • PIL.PsdImagePlugin • PIL.SunImagePlugin • PIL.TgaImagePlugin • PIL.TiffImagePlugin • PIL.XVThumbImagePlugin • PIL.XpmImagePlugin

PIL.ImageQt SourceModule

imports: 'PyQt6.QtGui' • 'PySide2.QtGui' • 'PySide6.QtGui' • PIL • PIL.Image • PIL._util • io • sys

imported by: PIL • PIL.Image

PIL.ImageSequence SourceModule

imports: PIL

imported by: PIL • PIL.GifImagePlugin • PIL.PdfImagePlugin • PIL.PngImagePlugin

PIL.ImageShow SourceModule

imports: PIL • PIL.Image • os • shlex • shutil • subprocess • sys • warnings

imported by: PIL • PIL.Image

PIL.ImageTk SourceModule

imports: PIL • PIL.Image • PIL._imagingtk • cffi • io

imported by: PIL • PIL.SpiderImagePlugin

PIL.ImtImagePlugin SourceModule

imports: PIL • PIL.Image • PIL.ImageFile • re

imported by: PIL.Image

PIL.IptcImagePlugin SourceModule

imports: PIL • PIL.Image • PIL.ImageFile • PIL.JpegImagePlugin • PIL.TiffImagePlugin • PIL._binary • io • os • tempfile

imported by: PIL.Image

PIL.Jpeg2KImagePlugin SourceModule

imports: PIL • PIL.Image • PIL.ImageFile • io • os • struct

imported by: PIL.IcnsImagePlugin • PIL.Image

PIL.JpegImagePlugin SourceModule

imports: PIL • PIL.Image • PIL.ImageFile • PIL.JpegPresets • PIL.MpoImagePlugin • PIL.TiffImagePlugin • PIL._binary • array • io • math • os • struct • subprocess • sys • tempfile • warnings

imported by: PIL • PIL.BlpImagePlugin • PIL.Image • PIL.IptcImagePlugin • PIL.MpoImagePlugin

PIL.JpegPresets SourceModule

imports: PIL

imported by: PIL.JpegImagePlugin

PIL.McIdasImagePlugin SourceModule

imports: PIL • PIL.Image • PIL.ImageFile • struct

imported by: PIL.Image

PIL.MicImagePlugin SourceModule

imports: PIL • PIL.Image • PIL.TiffImagePlugin • olefile

imported by: PIL.Image

PIL.MpegImagePlugin SourceModule

imports: PIL • PIL.Image • PIL.ImageFile • PIL._binary

imported by: PIL.Image

PIL.MpoImagePlugin SourceModule

imports: PIL • PIL.Image • PIL.ImageFile • PIL.JpegImagePlugin • PIL._binary

imported by: PIL.Image • PIL.JpegImagePlugin

PIL.MspImagePlugin SourceModule

imports: PIL • PIL.Image • PIL.ImageFile • PIL._binary • io • struct

imported by: PIL.Image

PIL.PaletteFile SourceModule

imports: PIL • PIL._binary

imported by: PIL • PIL.ImagePalette

PIL.PalmImagePlugin SourceModule

imports: PIL • PIL.Image • PIL.ImageFile • PIL._binary

imported by: PIL.Image

PIL.PcdImagePlugin SourceModule

imports: PIL • PIL.Image • PIL.ImageFile

imported by: PIL.Image

PIL.PcxImagePlugin SourceModule

imports: PIL • PIL.Image • PIL.ImageFile • PIL.ImagePalette • PIL._binary • io • logging

imported by: PIL.DcxImagePlugin • PIL.Image

PIL.PdfImagePlugin SourceModule

imports: PIL • PIL.Image • PIL.ImageFile • PIL.ImageSequence • PIL.PdfParser • io • os • time

imported by: PIL.Image

PIL.PdfParser SourceModule

imports: PIL • calendar • codecs • collections • mmap • os • re • time • zlib

imported by: PIL • PIL.PdfImagePlugin

PIL.PixarImagePlugin SourceModule

imports: PIL • PIL.Image • PIL.ImageFile • PIL._binary

imported by: PIL.Image

PIL.PngImagePlugin SourceModule

imports: PIL • PIL.Image • PIL.ImageChops • PIL.ImageFile • PIL.ImagePalette • PIL.ImageSequence • PIL._binary • enum • itertools • logging • re • struct • warnings • zlib

imported by: PIL • PIL.IcnsImagePlugin • PIL.IcoImagePlugin • PIL.Image • matplotlib.colors • matplotlib.image

PIL.PpmImagePlugin SourceModule

imports: PIL • PIL.Image • PIL.ImageFile • PIL._binary

imported by: PIL • PIL.Image

PIL.PsdImagePlugin SourceModule

imports: PIL • PIL.Image • PIL.ImageFile • PIL.ImagePalette • PIL._binary • io

imported by: PIL.Image

PIL.PyAccess SourceModule

imports: PIL • PIL._util • cffi • logging • sys

imported by: PIL • PIL.Image

PIL.SgiImagePlugin SourceModule

imports: PIL • PIL.Image • PIL.ImageFile • PIL._binary • os • struct

imported by: PIL.Image

PIL.SpiderImagePlugin SourceModule

imports: PIL • PIL.Image • PIL.ImageFile • PIL.ImageTk • os • struct • sys

imported by: PIL.Image

PIL.SunImagePlugin SourceModule

imports: PIL • PIL.Image • PIL.ImageFile • PIL.ImagePalette • PIL._binary

imported by: PIL.Image

PIL.TgaImagePlugin SourceModule

imports: PIL • PIL.Image • PIL.ImageFile • PIL.ImagePalette • PIL._binary • warnings

imported by: PIL.Image

PIL.TiffImagePlugin SourceModule

imports: PIL • PIL.Image • PIL.ImageFile • PIL.ImageOps • PIL.ImagePalette • PIL.TiffTags • PIL._binary • collections.abc • fractions • io • itertools • logging • math • numbers • os • struct • warnings

imported by: PIL • PIL.Image • PIL.IptcImagePlugin • PIL.JpegImagePlugin • PIL.MicImagePlugin

PIL.TiffTags SourceModule

imports: PIL • collections

imported by: PIL • PIL.Image • PIL.TiffImagePlugin

PIL.WebPImagePlugin SourceModule

imports: PIL • PIL.Image • PIL.ImageFile • PIL._webp • io

imported by: PIL.Image

PIL.WmfImagePlugin SourceModule

imports: PIL • PIL.Image • PIL.ImageFile • PIL._binary

imported by: PIL.Image

PIL.XVThumbImagePlugin SourceModule

imports: PIL • PIL.Image • PIL.ImageFile • PIL.ImagePalette • PIL._binary

imported by: PIL.Image

PIL.XbmImagePlugin SourceModule

imports: PIL • PIL.Image • PIL.ImageFile • re

imported by: PIL.Image

PIL.XpmImagePlugin SourceModule

imports: PIL • PIL.Image • PIL.ImageFile • PIL.ImagePalette • PIL._binary • re

imported by: PIL.Image

PIL._binary SourceModule

imports: PIL • struct

imported by: PIL.BmpImagePlugin • PIL.CurImagePlugin • PIL.DcxImagePlugin • PIL.DdsImagePlugin • PIL.EpsImagePlugin • PIL.FliImagePlugin • PIL.FpxImagePlugin • PIL.GbrImagePlugin • PIL.GifImagePlugin • PIL.GimpGradientFile • PIL.GimpPaletteFile • PIL.IcoImagePlugin • PIL.Image • PIL.IptcImagePlugin • PIL.JpegImagePlugin • PIL.MpegImagePlugin • PIL.MpoImagePlugin • PIL.MspImagePlugin • PIL.PaletteFile • PIL.PalmImagePlugin • PIL.PcxImagePlugin • PIL.PixarImagePlugin • PIL.PngImagePlugin • PIL.PpmImagePlugin • PIL.PsdImagePlugin • PIL.SgiImagePlugin • PIL.SunImagePlugin • PIL.TgaImagePlugin • PIL.TiffImagePlugin • PIL.WmfImagePlugin • PIL.XVThumbImagePlugin • PIL.XpmImagePlugin

PIL._imaging C:\Users\Giorgio\AppData\Local\Programs\Python\Python37\lib\site-packages\PIL\_imaging.cp37-win_amd64.pyd

imports: PIL

imported by: PIL • PIL.Image

PIL._imagingtk C:\Users\Giorgio\AppData\Local\Programs\Python\Python37\lib\site-packages\PIL\_imagingtk.cp37-win_amd64.pyd

imports: PIL

imported by: PIL • PIL.ImageTk

PIL._util SourceModule

imports: PIL • os • pathlib

imported by: PIL.Image • PIL.ImageFile • PIL.ImageQt • PIL.PyAccess

PIL._version SourceModule

imports: PIL

imported by: PIL

PIL._webp C:\Users\Giorgio\AppData\Local\Programs\Python\Python37\lib\site-packages\PIL\_webp.cp37-win_amd64.pyd

imports: PIL

imported by: PIL • PIL.WebPImagePlugin

PIL.features SourceModule

imports: PIL • PIL.Image • collections • os • sys • warnings

imported by: PIL • PIL.IcnsImagePlugin

PyQt4 MissingModule

imported by: pandas.io.clipboard

PyQt5 Package

imports: PyQt5.QtSvg • PyQt5.QtTest • PyQt5.sip • PyQt5.uic • os • pkgutil • sip • sys

imported by: PyQt5.QtCore • PyQt5.QtGui • PyQt5.QtSvg • PyQt5.QtTest • PyQt5.QtWidgets • PyQt5.sip • PyQt5.uic • PyQt5.uic.Loader.loader • PyQt5.uic.Loader.qobjectcreator • iAcc.py • matplotlib.backends.qt_compat • pandas.io.clipboard • pyqtgraph.GraphicsScene.exportDialogTemplate_pyqt5 • pyqtgraph.Qt • pyqtgraph.canvas.CanvasTemplate_pyqt5 • pyqtgraph.canvas.TransformGuiTemplate_pyqt5 • pyqtgraph.debug • pyqtgraph.examples.VideoTemplate_pyqt5 • pyqtgraph.examples.exampleLoaderTemplate_pyqt5 • pyqtgraph.flowchart.FlowchartCtrlTemplate_pyqt5 • pyqtgraph.flowchart.FlowchartTemplate_pyqt5 • pyqtgraph.graphicsItems.PlotItem.plotConfigTemplate_pyqt5 • pyqtgraph.graphicsItems.ViewBox.axisCtrlTemplate_pyqt5 • pyqtgraph.imageview.ImageViewTemplate_pyqt5

PyQt5.QtCore C:\Users\Giorgio\AppData\Local\Programs\Python\Python37\lib\site-packages\PyQt5\QtCore.pyd

imports: PyQt5 • PyQt5.QtCore

imported by: PyQt5.QtCore • PyQt5.QtGui • PyQt5.QtSvg • PyQt5.QtTest • PyQt5.QtWidgets • PyQt5.uic • PyQt5.uic.Loader.loader • iAcc.py • matplotlib.backends.qt_compat • pyqtgraph.GraphicsScene.exportDialogTemplate_pyqt5 • pyqtgraph.Qt • pyqtgraph.canvas.CanvasTemplate_pyqt5 • pyqtgraph.canvas.TransformGuiTemplate_pyqt5 • pyqtgraph.examples.VideoTemplate_pyqt5 • pyqtgraph.examples.exampleLoaderTemplate_pyqt5 • pyqtgraph.flowchart.FlowchartCtrlTemplate_pyqt5 • pyqtgraph.flowchart.FlowchartTemplate_pyqt5 • pyqtgraph.graphicsItems.PlotItem.plotConfigTemplate_pyqt5 • pyqtgraph.graphicsItems.ViewBox.axisCtrlTemplate_pyqt5 • pyqtgraph.imageview.ImageViewTemplate_pyqt5

PyQt5.QtGui C:\Users\Giorgio\AppData\Local\Programs\Python\Python37\lib\site-packages\PyQt5\QtGui.pyd

imports: PyQt5 • PyQt5.QtCore • PyQt5.QtGui

imported by: PyQt5.QtGui • PyQt5.QtSvg • PyQt5.QtTest • PyQt5.QtWidgets • PyQt5.uic.Loader.loader • PyQt5.uic.Loader.qobjectcreator • iAcc.py • matplotlib.backends.qt_compat • pyqtgraph.GraphicsScene.exportDialogTemplate_pyqt5 • pyqtgraph.Qt • pyqtgraph.canvas.CanvasTemplate_pyqt5 • pyqtgraph.canvas.TransformGuiTemplate_pyqt5 • pyqtgraph.examples.VideoTemplate_pyqt5 • pyqtgraph.examples.exampleLoaderTemplate_pyqt5 • pyqtgraph.flowchart.FlowchartCtrlTemplate_pyqt5 • pyqtgraph.flowchart.FlowchartTemplate_pyqt5 • pyqtgraph.graphicsItems.PlotItem.plotConfigTemplate_pyqt5 • pyqtgraph.graphicsItems.ViewBox.axisCtrlTemplate_pyqt5 • pyqtgraph.imageview.ImageViewTemplate_pyqt5

PyQt5.QtSvg C:\Users\Giorgio\AppData\Local\Programs\Python\Python37\lib\site-packages\PyQt5\QtSvg.pyd

imports: PyQt5 • PyQt5.QtCore • PyQt5.QtGui • PyQt5.QtSvg • PyQt5.QtWidgets

imported by: PyQt5 • PyQt5.QtSvg • pyqtgraph.Qt

PyQt5.QtTest C:\Users\Giorgio\AppData\Local\Programs\Python\Python37\lib\site-packages\PyQt5\QtTest.pyd

imports: PyQt5 • PyQt5.QtCore • PyQt5.QtGui • PyQt5.QtTest • PyQt5.QtWidgets

imported by: PyQt5 • PyQt5.QtTest • pyqtgraph.Qt

PyQt5.QtWidgets C:\Users\Giorgio\AppData\Local\Programs\Python\Python37\lib\site-packages\PyQt5\QtWidgets.pyd

imports: PyQt5 • PyQt5.QtCore • PyQt5.QtGui • PyQt5.QtWidgets

imported by: PyQt5.QtSvg • PyQt5.QtTest • PyQt5.QtWidgets • PyQt5.uic • PyQt5.uic.Loader.loader • PyQt5.uic.Loader.qobjectcreator • iAcc.py • matplotlib.backends.qt_compat • pandas.io.clipboard • pyqtgraph.GraphicsScene.exportDialogTemplate_pyqt5 • pyqtgraph.Qt • pyqtgraph.canvas.CanvasTemplate_pyqt5 • pyqtgraph.canvas.TransformGuiTemplate_pyqt5 • pyqtgraph.examples.VideoTemplate_pyqt5 • pyqtgraph.examples.exampleLoaderTemplate_pyqt5 • pyqtgraph.flowchart.FlowchartCtrlTemplate_pyqt5 • pyqtgraph.flowchart.FlowchartTemplate_pyqt5 • pyqtgraph.graphicsItems.PlotItem.plotConfigTemplate_pyqt5 • pyqtgraph.graphicsItems.ViewBox.axisCtrlTemplate_pyqt5 • pyqtgraph.imageview.ImageViewTemplate_pyqt5

PyQt5.sip C:\Users\Giorgio\AppData\Local\Programs\Python\Python37\lib\site-packages\PyQt5\sip.cp37-win_amd64.pyd

imports: PyQt5

imported by: PyQt5 • pyqtgraph.Qt • pyqtgraph.debug

PyQt5.uic Package

imports: PyQt5 • PyQt5.QtCore • PyQt5.QtWidgets • PyQt5.uic.Compiler • PyQt5.uic.Compiler.compiler • PyQt5.uic.Compiler.indenter • PyQt5.uic.Loader.loader • PyQt5.uic.objcreator • PyQt5.uic.port_v2.string_io • PyQt5.uic.port_v3.string_io • os • sys

imported by: PyQt5 • PyQt5.uic.Compiler • PyQt5.uic.Loader • PyQt5.uic.exceptions • PyQt5.uic.icon_cache • PyQt5.uic.objcreator • PyQt5.uic.port_v2 • PyQt5.uic.port_v3 • PyQt5.uic.properties • PyQt5.uic.uiparser • pyqtgraph.Qt

PyQt5.uic.Compiler Package

imports: PyQt5.uic • PyQt5.uic.Compiler • PyQt5.uic.Compiler.compiler • PyQt5.uic.Compiler.indenter • PyQt5.uic.Compiler.qtproxies

imported by: PyQt5.uic • PyQt5.uic.Compiler • PyQt5.uic.Compiler.compiler • PyQt5.uic.Compiler.indenter • PyQt5.uic.Compiler.misc • PyQt5.uic.Compiler.proxy_metaclass • PyQt5.uic.Compiler.qobjectcreator • PyQt5.uic.Compiler.qtproxies

PyQt5.uic.Compiler.compiler SourceModule

imports: PyQt5.uic.Compiler • PyQt5.uic.Compiler.indenter • PyQt5.uic.Compiler.qobjectcreator • PyQt5.uic.Compiler.qtproxies • PyQt5.uic.properties • PyQt5.uic.uiparser • sys

imported by: PyQt5.uic • PyQt5.uic.Compiler

PyQt5.uic.Compiler.indenter SourceModule

imports: PyQt5.uic.Compiler

imported by: PyQt5.uic • PyQt5.uic.Compiler • PyQt5.uic.Compiler.compiler • PyQt5.uic.Compiler.qobjectcreator • PyQt5.uic.Compiler.qtproxies

PyQt5.uic.Compiler.misc SourceModule

imports: PyQt5.uic.Compiler

imported by: PyQt5.uic.Compiler.proxy_metaclass • PyQt5.uic.Compiler.qtproxies

PyQt5.uic.Compiler.proxy_metaclass SourceModule

imports: PyQt5.uic.Compiler • PyQt5.uic.Compiler.misc • PyQt5.uic.Compiler.qtproxies

imported by: PyQt5.uic.port_v2.proxy_base • PyQt5.uic.port_v3.proxy_base

PyQt5.uic.Compiler.qobjectcreator SourceModule

imports: PyQt5.uic.Compiler • PyQt5.uic.Compiler.indenter • PyQt5.uic.Compiler.qtproxies • PyQt5.uic.port_v2.as_string • PyQt5.uic.port_v3.as_string • logging • sys

imported by: PyQt5.uic.Compiler.compiler

PyQt5.uic.Compiler.qtproxies SourceModule

imports: PyQt5.uic.Compiler • PyQt5.uic.Compiler.indenter • PyQt5.uic.Compiler.misc • PyQt5.uic.port_v2.as_string • PyQt5.uic.port_v2.proxy_base • PyQt5.uic.port_v3.as_string • PyQt5.uic.port_v3.proxy_base • re • sys

imported by: PyQt5.uic.Compiler • PyQt5.uic.Compiler.compiler • PyQt5.uic.Compiler.proxy_metaclass • PyQt5.uic.Compiler.qobjectcreator

PyQt5.uic.Loader Package

imports: PyQt5.uic

imported by: PyQt5.uic.Loader.loader • PyQt5.uic.Loader.qobjectcreator

PyQt5.uic.Loader.loader SourceModule

imports: PyQt5 • PyQt5.QtCore • PyQt5.QtGui • PyQt5.QtWidgets • PyQt5.uic.Loader • PyQt5.uic.Loader.qobjectcreator • PyQt5.uic.uiparser

imported by: PyQt5.uic

PyQt5.uic.Loader.qobjectcreator SourceModule

imports: PyQt5 • PyQt5.QtGui • PyQt5.QtWidgets • PyQt5.uic.Loader • sys

imported by: PyQt5.uic.Loader.loader

PyQt5.uic.exceptions SourceModule

imports: PyQt5.uic

imported by: PyQt5.uic.objcreator • PyQt5.uic.properties

PyQt5.uic.icon_cache SourceModule

imports: PyQt5.uic • ntpath

imported by: PyQt5.uic.properties

PyQt5.uic.objcreator SourceModule

imports: PyQt5.uic • PyQt5.uic.exceptions • ntpath

imported by: PyQt5.uic • PyQt5.uic.uiparser

PyQt5.uic.port_v2 Package

imports: PyQt5.uic

imported by: PyQt5.uic.port_v2.as_string • PyQt5.uic.port_v2.proxy_base • PyQt5.uic.port_v2.string_io

PyQt5.uic.port_v2.as_string SourceModule

imports: PyQt5.uic.port_v2 • re

imported by: PyQt5.uic.Compiler.qobjectcreator • PyQt5.uic.Compiler.qtproxies

PyQt5.uic.port_v2.proxy_base SourceModule

imports: PyQt5.uic.Compiler.proxy_metaclass • PyQt5.uic.port_v2

imported by: PyQt5.uic.Compiler.qtproxies

PyQt5.uic.port_v2.string_io SourceModule

imports: PyQt5.uic.port_v2 • StringIO • cStringIO

imported by: PyQt5.uic

PyQt5.uic.port_v3 Package

imports: PyQt5.uic

imported by: PyQt5.uic.port_v3.as_string • PyQt5.uic.port_v3.ascii_upper • PyQt5.uic.port_v3.proxy_base • PyQt5.uic.port_v3.string_io

PyQt5.uic.port_v3.as_string SourceModule

imports: PyQt5.uic.port_v3 • re

imported by: PyQt5.uic.Compiler.qobjectcreator • PyQt5.uic.Compiler.qtproxies

PyQt5.uic.port_v3.ascii_upper SourceModule

imports: PyQt5.uic.port_v3

imported by: PyQt5.uic.properties

PyQt5.uic.port_v3.proxy_base SourceModule

imports: PyQt5.uic.Compiler.proxy_metaclass • PyQt5.uic.port_v3

imported by: PyQt5.uic.Compiler.qtproxies

PyQt5.uic.port_v3.string_io SourceModule

imports: PyQt5.uic.port_v3 • io

imported by: PyQt5.uic

PyQt5.uic.properties SourceModule

imports: PyQt5.uic • PyQt5.uic.exceptions • PyQt5.uic.icon_cache • PyQt5.uic.port_v3.ascii_upper • logging • ntpath • port_v2 • sys

imported by: PyQt5.uic.Compiler.compiler • PyQt5.uic.uiparser

PyQt5.uic.uiparser SourceModule

imports: PyQt5.uic • PyQt5.uic.objcreator • PyQt5.uic.properties • logging • os • re • sys • xml.etree.ElementTree

imported by: PyQt5.uic.Compiler.compiler • PyQt5.uic.Loader.loader

PyQt6 MissingModule

imported by: matplotlib.backends.backend_qtagg • matplotlib.backends.qt_compat • pyqtgraph.GraphicsScene.exportDialogTemplate_pyqt6 • pyqtgraph.Qt • pyqtgraph.canvas.CanvasTemplate_pyqt6 • pyqtgraph.canvas.TransformGuiTemplate_pyqt6 • pyqtgraph.examples.VideoTemplate_pyqt6 • pyqtgraph.examples.exampleLoaderTemplate_pyqt6 • pyqtgraph.flowchart.FlowchartCtrlTemplate_pyqt6 • pyqtgraph.flowchart.FlowchartTemplate_pyqt6 • pyqtgraph.graphicsItems.PlotItem.plotConfigTemplate_pyqt6 • pyqtgraph.graphicsItems.ViewBox.axisCtrlTemplate_pyqt6 • pyqtgraph.imageview.ImageViewTemplate_pyqt6

PySide2 MissingModule

imported by: matplotlib.backends.qt_compat • pyqtgraph.Qt • pyqtgraph.canvas.CanvasTemplate_pyside2 • pyqtgraph.canvas.TransformGuiTemplate_pyside2 • pyqtgraph.flowchart.FlowchartCtrlTemplate_pyside2 • pyqtgraph.flowchart.FlowchartTemplate_pyside2 • pyqtgraph.graphicsItems.PlotItem.plotConfigTemplate_pyside2 • pyqtgraph.graphicsItems.ViewBox.axisCtrlTemplate_pyside2 • pyqtgraph.imageview.ImageViewTemplate_pyside2

PySide6 MissingModule

imported by: matplotlib.backends.qt_compat • pyqtgraph.Qt

StringIO MissingModule

imported by: PyInstaller.lib.modulegraph._compat • PyInstaller.lib.modulegraph.zipio • PyQt5.uic.port_v2.string_io • pkg_resources._vendor.six • setuptools._vendor.six • six

System MissingModule

imported by: serial.serialcli

UserDict MissingModule

imported by: pytz.lazy

__builtin__ MissingModule

imported by: pkg_resources._vendor.pyparsing • pyqtgraph.multiprocess.remoteproxy • setuptools._vendor.pyparsing

__future__ SourceModule

imported by: codeop • dateutil.parser._parser • doctest • numpy.typing._array_like • numpy.typing._generic_alias • ordlookup • pandas._config.config • pandas._config.display • pandas._testing • pandas._testing._io • pandas._testing._warnings • pandas._testing.asserters • pandas._testing.contexts • pandas.compat._optional • pandas.compat.numpy.function • pandas.compat.pickle_compat • pandas.core.accessor • pandas.core.aggregation • pandas.core.algorithms • pandas.core.apply • pandas.core.array_algos.putmask • pandas.core.array_algos.quantile • pandas.core.array_algos.replace • pandas.core.array_algos.take • pandas.core.arrays._mixins • pandas.core.arrays._ranges • pandas.core.arrays.base • pandas.core.arrays.boolean • pandas.core.arrays.categorical • pandas.core.arrays.datetimelike • pandas.core.arrays.datetimes • pandas.core.arrays.floating • pandas.core.arrays.integer • pandas.core.arrays.interval • pandas.core.arrays.masked • pandas.core.arrays.numeric • pandas.core.arrays.numpy_ • pandas.core.arrays.period • pandas.core.arrays.sparse.array • pandas.core.arrays.sparse.dtype • pandas.core.arrays.string_ • pandas.core.arrays.string_arrow • pandas.core.arrays.timedeltas • pandas.core.base • pandas.core.common • pandas.core.computation.align • pandas.core.computation.engines • pandas.core.computation.eval • pandas.core.computation.expr • pandas.core.computation.expressions • pandas.core.computation.ops • pandas.core.computation.parsing • pandas.core.computation.pytables • pandas.core.computation.scope • pandas.core.construction • pandas.core.describe • pandas.core.dtypes.base • pandas.core.dtypes.cast • pandas.core.dtypes.common • pandas.core.dtypes.dtypes • pandas.core.dtypes.generic • pandas.core.frame • pandas.core.generic • pandas.core.groupby.base • pandas.core.groupby.categorical • pandas.core.groupby.generic • pandas.core.groupby.groupby • pandas.core.groupby.grouper • pandas.core.groupby.numba_ • pandas.core.groupby.ops • pandas.core.indexers • pandas.core.indexes.accessors • pandas.core.indexes.api • pandas.core.indexes.base • pandas.core.indexes.category • pandas.core.indexes.datetimelike • pandas.core.indexes.datetimes • pandas.core.indexes.extension • pandas.core.indexes.frozen • pandas.core.indexes.interval • pandas.core.indexes.multi • pandas.core.indexes.numeric • pandas.core.indexes.period • pandas.core.indexes.range • pandas.core.indexes.timedeltas • pandas.core.indexing • pandas.core.internals.api • pandas.core.internals.array_manager • pandas.core.internals.base • pandas.core.internals.blocks • pandas.core.internals.concat • pandas.core.internals.construction • pandas.core.internals.managers • pandas.core.internals.ops • pandas.core.missing • pandas.core.nanops • pandas.core.ops • pandas.core.ops.docstrings • pandas.core.ops.mask_ops • pandas.core.resample • pandas.core.reshape.concat • pandas.core.reshape.melt • pandas.core.reshape.merge • pandas.core.reshape.pivot • pandas.core.reshape.reshape • pandas.core.series • pandas.core.shared_docs • pandas.core.sorting • pandas.core.strings.accessor • pandas.core.strings.base • pandas.core.strings.object_array • pandas.core.tools.datetimes • pandas.core.tools.numeric • pandas.core.tools.times • pandas.core.util.hashing • pandas.core.util.numba_ • pandas.core.window.ewm • pandas.core.window.expanding • pandas.core.window.indexers • pandas.core.window.numba_ • pandas.core.window.rolling • pandas.io.common • pandas.io.excel._base • pandas.io.excel._odfreader • pandas.io.excel._odswriter • pandas.io.excel._openpyxl • pandas.io.excel._pyxlsb • pandas.io.excel._util • pandas.io.excel._xlsxwriter • pandas.io.excel._xlwt • pandas.io.formats.css • pandas.io.formats.csvs • pandas.io.formats.excel • pandas.io.formats.format • pandas.io.formats.html • pandas.io.formats.info • pandas.io.formats.latex • pandas.io.formats.printing • pandas.io.formats.string • pandas.io.formats.style • pandas.io.formats.style_render • pandas.io.formats.xml • pandas.io.gbq • pandas.io.html • pandas.io.json._json • pandas.io.json._normalize • pandas.io.json._table_schema • pandas.io.orc • pandas.io.parquet • pandas.io.parsers.base_parser • pandas.io.parsers.c_parser_wrapper • pandas.io.parsers.python_parser • pandas.io.parsers.readers • pandas.io.pytables • pandas.io.sas.sas7bdat • pandas.io.sas.sasreader • pandas.io.spss • pandas.io.sql • pandas.io.stata • pandas.io.xml • pandas.plotting._core • pandas.plotting._matplotlib • pandas.plotting._matplotlib.boxplot • pandas.plotting._matplotlib.converter • pandas.plotting._matplotlib.core • pandas.plotting._matplotlib.hist • pandas.plotting._matplotlib.misc • pandas.plotting._matplotlib.style • pandas.plotting._matplotlib.timeseries • pandas.plotting._matplotlib.tools • pandas.tseries.frequencies • pandas.util._decorators • pandas.util._exceptions • pandas.util._print_versions • pandas.util._validators • pandas.util.version • pkg_resources • pkg_resources._vendor.packaging • pkg_resources._vendor.packaging.__about__ • pkg_resources._vendor.packaging._compat • pkg_resources._vendor.packaging._structures • pkg_resources._vendor.packaging.markers • pkg_resources._vendor.packaging.requirements • pkg_resources._vendor.packaging.specifiers • pkg_resources._vendor.packaging.utils • pkg_resources._vendor.packaging.version • pkg_resources._vendor.six • pyqtgraph.debug • pyqtgraph.functions • pyqtgraph.reload • scipy.integrate._quadrature • scipy.optimize._trustregion_constr.report • scipy.spatial._geometric_slerp • scipy.stats._entropy • scipy.stats._qmc • scipy.stats.morestats • serial • serial.serialcli • serial.serialjava • serial.serialposix • serial.serialutil • serial.serialwin32 • serial.tools.list_ports • serial.tools.list_ports_common • serial.tools.list_ports_linux • serial.tools.list_ports_osx • serial.tools.list_ports_posix • serial.tools.list_ports_windows • serial.win32 • setuptools._vendor.packaging • setuptools._vendor.packaging.__about__ • setuptools._vendor.packaging._compat • setuptools._vendor.packaging._structures • setuptools._vendor.packaging.markers • setuptools._vendor.packaging.requirements • setuptools._vendor.packaging.specifiers • setuptools._vendor.packaging.utils • setuptools._vendor.packaging.version • setuptools._vendor.six • setuptools.config • setuptools.glibc • setuptools.pep425tags • six • win32ctypes.core • win32ctypes.core.ctypes._authentication • win32ctypes.core.ctypes._common • win32ctypes.core.ctypes._dll • win32ctypes.core.ctypes._nl_support • win32ctypes.core.ctypes._resource • win32ctypes.core.ctypes._system_information • win32ctypes.core.ctypes._time • win32ctypes.core.ctypes._util • win32ctypes.pywin32 • win32ctypes.pywin32.pywintypes • win32ctypes.pywin32.win32api • win32ctypes.pywin32.win32cred

_abc (builtin module)

imported by: abc

_ast (builtin module)

imported by: ast

_asyncio C:\Users\Giorgio\AppData\Local\Programs\Python\Python37\DLLs\_asyncio.pyd

imported by: asyncio.events • asyncio.futures • asyncio.tasks

_bisect (builtin module)

imported by: bisect

_blake2 (builtin module)

imported by: hashlib

_bootlocale SourceModule

imports: _locale • locale • sys

imported by: iAcc.py • locale

_bz2 C:\Users\Giorgio\AppData\Local\Programs\Python\Python37\DLLs\_bz2.pyd

imported by: bz2

_codecs (builtin module)

imported by: codecs

_codecs_cn (builtin module)

imported by: encodings.gb18030 • encodings.gb2312 • encodings.gbk • encodings.hz

_codecs_hk (builtin module)

imported by: encodings.big5hkscs

_codecs_iso2022 (builtin module)

imported by: encodings.iso2022_jp • encodings.iso2022_jp_1 • encodings.iso2022_jp_2 • encodings.iso2022_jp_2004 • encodings.iso2022_jp_3 • encodings.iso2022_jp_ext • encodings.iso2022_kr

_codecs_jp (builtin module)

imported by: encodings.cp932 • encodings.euc_jis_2004 • encodings.euc_jisx0213 • encodings.euc_jp • encodings.shift_jis • encodings.shift_jis_2004 • encodings.shift_jisx0213

_codecs_kr (builtin module)

imported by: encodings.cp949 • encodings.euc_kr • encodings.johab

_codecs_tw (builtin module)

imported by: encodings.big5 • encodings.cp950

_collections (builtin module)

imported by: collections • enum • threading

_collections_abc SourceModule

imports: abc • sys

imported by: collections • collections.abc • contextlib • iAcc.py • locale • os • pathlib • random • types • typing_extensions • weakref

_compat_pickle SourceModule

imported by: _pickle • pickle

_compression SourceModule

imports: io

imported by: bz2 • gzip • lzma

_contextvars (builtin module)

imported by: contextvars

_csv (builtin module)

imported by: csv

_ctypes C:\Users\Giorgio\AppData\Local\Programs\Python\Python37\DLLs\_ctypes.pyd

imported by: ctypes • numpy.core._dtype_ctypes

_curses MissingModule

imports: curses

imported by: curses • curses.has_key

_datetime (builtin module)

imports: _strptime • time

imported by: datetime

_decimal C:\Users\Giorgio\AppData\Local\Programs\Python\Python37\DLLs\_decimal.pyd

imported by: decimal

_dummy_thread SourceModule

imports: time • traceback

imported by: dummy_threading • numpy.core.arrayprint

_dummy_threading MissingModule

imported by: dummy_threading

_elementtree C:\Users\Giorgio\AppData\Local\Programs\Python\Python37\DLLs\_elementtree.pyd

imports: pyexpat • xml.etree.ElementInclude • xml.etree.ElementPath • xml.etree.ElementTree • xml.etree.cElementTree

imported by: xml.etree.ElementTree

_frozen_importlib ExcludedModule

imported by: PyInstaller.loader.pyimod02_archive • importlib • importlib.abc

_frozen_importlib_external MissingModule

imported by: importlib • importlib._bootstrap • importlib.abc

_functools (builtin module)

imported by: functools

_hashlib C:\Users\Giorgio\AppData\Local\Programs\Python\Python37\DLLs\_hashlib.pyd

imported by: hashlib • hmac

_heapq (builtin module)

imported by: heapq

_imp (builtin module)

imported by: distutils.sysconfig • imp • importlib • importlib.machinery • importlib.util • pkg_resources

_io (builtin module)

imported by: io

_json (builtin module)

imports: json.decoder

imported by: json.decoder • json.encoder • json.scanner

_locale (builtin module)

imported by: _bootlocale • locale • re

_lsprof (builtin module)

imported by: cProfile

_lzma C:\Users\Giorgio\AppData\Local\Programs\Python\Python37\DLLs\_lzma.pyd

imported by: lzma

_manylinux MissingModule

imported by: packaging._manylinux • setuptools.pep425tags

_markupbase SourceModule

imports: re

imported by: html.parser

_md5 (builtin module)

imported by: hashlib

_multibytecodec (builtin module)

imported by: encodings.big5 • encodings.big5hkscs • encodings.cp932 • encodings.cp949 • encodings.cp950 • encodings.euc_jis_2004 • encodings.euc_jisx0213 • encodings.euc_jp • encodings.euc_kr • encodings.gb18030 • encodings.gb2312 • encodings.gbk • encodings.hz • encodings.iso2022_jp • encodings.iso2022_jp_1 • encodings.iso2022_jp_2 • encodings.iso2022_jp_2004 • encodings.iso2022_jp_3 • encodings.iso2022_jp_ext • encodings.iso2022_kr • encodings.johab • encodings.shift_jis • encodings.shift_jis_2004 • encodings.shift_jisx0213

_multiprocessing C:\Users\Giorgio\AppData\Local\Programs\Python\Python37\DLLs\_multiprocessing.pyd

imported by: multiprocessing.connection • multiprocessing.queues • multiprocessing.semaphore_tracker • multiprocessing.synchronize

_opcode (builtin module)

imported by: opcode

_operator (builtin module)

imported by: hmac • operator

_osx_support SourceModule

imports: contextlib • distutils • distutils.log • os • re • sys • tempfile

imported by: distutils.sysconfig • distutils.unixccompiler • distutils.util

_overlapped C:\Users\Giorgio\AppData\Local\Programs\Python\Python37\DLLs\_overlapped.pyd

imported by: asyncio.windows_events

_pickle (builtin module)

imports: _compat_pickle • codecs • copyreg

imported by: pickle

_posixsubprocess MissingModule

imports: gc

imported by: multiprocessing.util • subprocess

_py_abc SourceModule

imports: _weakrefset

imported by: abc

_pydecimal SourceModule

imports: collections • contextvars • itertools • locale • math • numbers • re • sys

imported by: decimal

_queue C:\Users\Giorgio\AppData\Local\Programs\Python\Python37\DLLs\_queue.pyd

imported by: queue

_random (builtin module)

imported by: random

_scproxy MissingModule

imported by: urllib.request

_sha1 (builtin module)

imported by: hashlib

_sha256 (builtin module)

imported by: hashlib

_sha3 (builtin module)

imported by: hashlib

_sha512 (builtin module)

imported by: hashlib

_signal (builtin module)

imported by: signal

_socket C:\Users\Giorgio\AppData\Local\Programs\Python\Python37\DLLs\_socket.pyd

imported by: socket

_sqlite3 C:\Users\Giorgio\AppData\Local\Programs\Python\Python37\DLLs\_sqlite3.pyd

imported by: sqlite3.dbapi2

_sre (builtin module)

imports: copy • re

imported by: sre_compile • sre_constants

_ssl C:\Users\Giorgio\AppData\Local\Programs\Python\Python37\DLLs\_ssl.pyd

imports: socket

imported by: ssl

_stat (builtin module)

imported by: stat

_string (builtin module)

imported by: string

_strptime SourceModule

imports: _thread • calendar • datetime • locale • re • time

imported by: _datetime • datetime • time

_struct (builtin module)

imported by: struct

_thread (builtin module)

imported by: PyInstaller.loader.pyimod02_archive • _strptime • _thread • dataclasses • functools • numpy.core.arrayprint • pkg_resources._vendor.pyparsing • reprlib • setuptools._vendor.pyparsing • telnetlib • tempfile • threading

_thread AliasNode

imports: _thread

imported by: dateutil.rrule • dateutil.tz._factories • dateutil.tz.tz • six.moves

_threading_local SourceModule

imports: contextlib • threading • weakref

imported by: threading

_tracemalloc (builtin module)

imported by: tracemalloc

_ufunc MissingModule

imported by: numpy.typing

_uuid MissingModule

imported by: uuid

_warnings (builtin module)

imported by: warnings

_weakref (builtin module)

imported by: _weakrefset • collections • weakref • xml.sax.expatreader

_weakrefset SourceModule

imports: _weakref

imported by: _py_abc • iAcc.py • multiprocessing.process • threading • weakref

_winapi (builtin module)

imported by: asyncio.windows_events • asyncio.windows_utils • encodings • multiprocessing.connection • multiprocessing.heap • multiprocessing.popen_spawn_win32 • multiprocessing.reduction • subprocess

_winreg MissingModule

imported by: pkg_resources._vendor.appdirs • platform

abc SourceModule

imports: _abc • _py_abc

imported by: _collections_abc • contextlib • email._policybase • functools • iAcc.py • importlib.abc • importlib_metadata • inspect • io • multiprocessing.reduction • numbers • numpy.compat.py3k • numpy.polynomial._polybase • os • packaging.specifiers • pandas.core.apply • pandas.core.computation.engines • pandas.core.describe • pandas.core.strings.base • pandas.io.excel._base • pandas.io.formats.info • pandas.io.formats.latex • pandas.io.json._json • pandas.io.sas.sasreader • pkg_resources._vendor.packaging.specifiers • pyparsing.core • scipy.stats._qmc • selectors • setuptools._vendor.packaging.specifiers • typing • typing_extensions

argparse SourceModule

imports: copy • gettext • os • re • sys • textwrap • warnings

imported by: PyInstaller.__main__ • PyInstaller.building.makespec • calendar • code • dis • doctest • http.server • inspect • matplotlib.dviread • pyqtgraph.examples.ExampleApp • serial.tools.list_ports • tarfile • tokenize • unittest.main • zipfile

array (builtin module)

imported by: PIL.ImagePalette • PIL.JpegImagePlugin • multiprocessing.dummy • multiprocessing.managers • multiprocessing.reduction • pkg_resources._vendor.appdirs • serial.serialposix • serial.serialutil • setuptools.py33compat

ast SourceModule

imports: _ast • collections • inspect

imported by: PyInstaller.depend.analysis • PyInstaller.lib.modulegraph.modulegraph • inspect • matplotlib.rcsetup • numpy.core._internal • numpy.lib.utils • numpy.matrixlib.defmatrix • pandas.core.computation.expr • pandas.core.computation.pytables

asyncio Package

imports: asyncio • asyncio.DefaultEventLoopPolicy • asyncio.base_events • asyncio.base_futures • asyncio.base_subprocess • asyncio.base_tasks • asyncio.constants • asyncio.coroutines • asyncio.events • asyncio.format_helpers • asyncio.futures • asyncio.locks • asyncio.proactor_events • asyncio.protocols • asyncio.queues • asyncio.runners • asyncio.selector_events • asyncio.sslproto • asyncio.streams • asyncio.subprocess • asyncio.tasks • asyncio.transports • asyncio.unix_events • asyncio.windows_events • asyncio.windows_utils • sys

imported by: asyncio • asyncio.base_events • asyncio.base_futures • asyncio.base_subprocess • asyncio.base_tasks • asyncio.constants • asyncio.coroutines • asyncio.events • asyncio.format_helpers • asyncio.futures • asyncio.locks • asyncio.log • asyncio.proactor_events • asyncio.protocols • asyncio.queues • asyncio.runners • asyncio.selector_events • asyncio.sslproto • asyncio.streams • asyncio.subprocess • asyncio.tasks • asyncio.transports • asyncio.unix_events • asyncio.windows_events • asyncio.windows_utils • matplotlib.backends.backend_webagg_core

asyncio.DefaultEventLoopPolicy MissingModule

imported by: asyncio • asyncio.events

asyncio.base_events SourceModule

imports: asyncio • asyncio.constants • asyncio.coroutines • asyncio.events • asyncio.futures • asyncio.log • asyncio.protocols • asyncio.sslproto • asyncio.tasks • asyncio.transports • collections • collections.abc • concurrent.futures • heapq • itertools • logging • os • socket • ssl • subprocess • sys • threading • time • traceback • warnings • weakref

imported by: asyncio • asyncio.proactor_events • asyncio.selector_events • asyncio.sslproto • asyncio.unix_events

asyncio.base_futures SourceModule

imports: asyncio • asyncio.format_helpers • concurrent.futures._base • reprlib

imported by: asyncio • asyncio.base_tasks • asyncio.coroutines • asyncio.futures

asyncio.base_subprocess SourceModule

imports: asyncio • asyncio.log • asyncio.protocols • asyncio.transports • collections • subprocess • warnings

imported by: asyncio • asyncio.unix_events • asyncio.windows_events

asyncio.base_tasks SourceModule

imports: asyncio • asyncio.base_futures • asyncio.coroutines • linecache • traceback

imported by: asyncio • asyncio.tasks

asyncio.constants SourceModule

imports: asyncio • enum

imported by: asyncio • asyncio.base_events • asyncio.coroutines • asyncio.format_helpers • asyncio.proactor_events • asyncio.selector_events • asyncio.sslproto • asyncio.unix_events

asyncio.coroutines SourceModule

imports: asyncio • asyncio.base_futures • asyncio.constants • asyncio.format_helpers • asyncio.log • collections.abc • functools • inspect • os • sys • traceback • types

imported by: asyncio • asyncio.base_events • asyncio.base_tasks • asyncio.locks • asyncio.runners • asyncio.streams • asyncio.tasks • asyncio.unix_events

asyncio.events SourceModule

imports: _asyncio • asyncio • asyncio.DefaultEventLoopPolicy • asyncio.format_helpers • contextvars • os • socket • subprocess • sys • threading

imported by: asyncio • asyncio.base_events • asyncio.futures • asyncio.locks • asyncio.proactor_events • asyncio.queues • asyncio.runners • asyncio.selector_events • asyncio.streams • asyncio.subprocess • asyncio.tasks • asyncio.unix_events • asyncio.windows_events

asyncio.format_helpers SourceModule

imports: asyncio • asyncio.constants • functools • inspect • reprlib • sys • traceback

imported by: asyncio • asyncio.base_futures • asyncio.coroutines • asyncio.events • asyncio.futures

asyncio.futures SourceModule

imports: _asyncio • asyncio • asyncio.base_futures • asyncio.events • asyncio.format_helpers • concurrent.futures • contextvars • logging • sys

imported by: asyncio • asyncio.base_events • asyncio.locks • asyncio.proactor_events • asyncio.selector_events • asyncio.tasks • asyncio.unix_events • asyncio.windows_events

asyncio.locks SourceModule

imports: asyncio • asyncio.coroutines • asyncio.events • asyncio.futures • collections • warnings

imported by: asyncio • asyncio.queues

asyncio.log SourceModule

imports: asyncio • logging

imported by: asyncio.base_events • asyncio.base_subprocess • asyncio.coroutines • asyncio.proactor_events • asyncio.selector_events • asyncio.sslproto • asyncio.streams • asyncio.subprocess • asyncio.unix_events • asyncio.windows_events

asyncio.proactor_events SourceModule

imports: asyncio • asyncio.base_events • asyncio.constants • asyncio.events • asyncio.futures • asyncio.log • asyncio.protocols • asyncio.sslproto • asyncio.transports • io • os • socket • warnings

imported by: asyncio • asyncio.windows_events

asyncio.protocols SourceModule

imports: asyncio

imported by: asyncio • asyncio.base_events • asyncio.base_subprocess • asyncio.proactor_events • asyncio.selector_events • asyncio.sslproto • asyncio.streams • asyncio.subprocess

asyncio.queues SourceModule

imports: asyncio • asyncio.events • asyncio.locks • collections • heapq

imported by: asyncio • asyncio.tasks

asyncio.runners SourceModule

imports: asyncio • asyncio.coroutines • asyncio.events • asyncio.tasks

imported by: asyncio

asyncio.selector_events SourceModule

imports: asyncio • asyncio.base_events • asyncio.constants • asyncio.events • asyncio.futures • asyncio.log • asyncio.protocols • asyncio.sslproto • asyncio.transports • collections • errno • functools • selectors • socket • ssl • warnings • weakref

imported by: asyncio • asyncio.unix_events • asyncio.windows_events

asyncio.sslproto SourceModule

imports: asyncio • asyncio.base_events • asyncio.constants • asyncio.log • asyncio.protocols • asyncio.transports • collections • ssl • warnings

imported by: asyncio • asyncio.base_events • asyncio.proactor_events • asyncio.selector_events

asyncio.streams SourceModule

imports: asyncio • asyncio.coroutines • asyncio.events • asyncio.log • asyncio.protocols • asyncio.tasks • socket

imported by: asyncio • asyncio.subprocess

asyncio.subprocess SourceModule

imports: asyncio • asyncio.events • asyncio.log • asyncio.protocols • asyncio.streams • asyncio.tasks • subprocess

imported by: asyncio

asyncio.tasks SourceModule

imports: _asyncio • asyncio • asyncio.base_tasks • asyncio.coroutines • asyncio.events • asyncio.futures • asyncio.queues • concurrent.futures • contextvars • functools • inspect • types • warnings • weakref

imported by: asyncio • asyncio.base_events • asyncio.runners • asyncio.streams • asyncio.subprocess • asyncio.unix_events • asyncio.windows_events

asyncio.transports SourceModule

imports: asyncio

imported by: asyncio • asyncio.base_events • asyncio.base_subprocess • asyncio.proactor_events • asyncio.selector_events • asyncio.sslproto • asyncio.unix_events

asyncio.unix_events SourceModule

imports: asyncio • asyncio.base_events • asyncio.base_subprocess • asyncio.constants • asyncio.coroutines • asyncio.events • asyncio.futures • asyncio.log • asyncio.selector_events • asyncio.tasks • asyncio.transports • errno • io • os • selectors • signal • socket • stat • subprocess • sys • threading • warnings

imported by: asyncio

asyncio.windows_events SourceModule

imports: _overlapped • _winapi • asyncio • asyncio.base_subprocess • asyncio.events • asyncio.futures • asyncio.log • asyncio.proactor_events • asyncio.selector_events • asyncio.tasks • asyncio.windows_utils • errno • math • msvcrt • socket • struct • time • weakref

imported by: asyncio

asyncio.windows_utils SourceModule

imports: _winapi • asyncio • itertools • msvcrt • os • subprocess • sys • tempfile • warnings

imported by: asyncio • asyncio.windows_events

atexit (builtin module)

imported by: PIL.Image • concurrent.futures.process • concurrent.futures.thread • logging • matplotlib • matplotlib._pylab_helpers • multiprocessing.util • numpy.distutils.ccompiler_opt • numpy.distutils.command.build_clib • numpy.distutils.command.build_ext • numpy.distutils.misc_util • pyi_rth_mplconfig.py • pyqtgraph • pyqtgraph.multiprocess.processes • pyqtgraph.widgets.RemoteGraphicsView • scipy._lib._uarray._backend • setuptools.ssl_support • weakref

backports MissingModule

imported by: setuptools.ssl_support

base64 SourceModule

imports: binascii • getopt • re • struct • sys • warnings

imported by: PyInstaller.isolated._parent • email._encoded_words • email.base64mime • email.encoders • encodings.base64_codec • http.server • matplotlib.colors • setuptools.package_index • ssl • urllib.request • xmlrpc.client

bdb SourceModule

imports: fnmatch • inspect • linecache • os • reprlib • sys

imported by: pdb

binascii (builtin module)

imported by: base64 • email._encoded_words • email.base64mime • email.contentmanager • email.header • encodings.hex_codec • encodings.uu_codec • http.server • plistlib • quopri • uu • zipfile

bisect SourceModule

imports: _bisect

imported by: dateutil.tz.tz • multiprocessing.heap • pytz.tzinfo • random • scipy.sparse.lil • urllib.request

botocore MissingModule

imported by: pandas.io.common

bottleneck MissingModule

imported by: pyqtgraph.imageview.ImageView

bs4 MissingModule

imported by: pandas.io.html

builtins (builtin module)

imported by: PIL.Image • builtins • bz2 • codecs • dataclasses • doctest • gettext • gzip • inspect • locale • lzma • matplotlib.axes._axes • numpy • numpy.core.numerictypes • numpy.distutils.misc_util • numpy.lib.function_base • numpy.ma.core • operator • pandas.core.common • pydoc • pyqtgraph.multiprocess.remoteproxy • pyqtgraph.parametertree.parameterTypes.basetypes • reprlib • scipy.stats._binned_statistic • subprocess • tarfile • tokenize

builtins AliasNode

imports: builtins

imported by: setuptools.extern.six.moves • setuptools.sandbox

bz2 SourceModule

imports: _bz2 • _compression • builtins • io • os • threading • warnings

imported by: encodings.bz2_codec • fileinput • matplotlib.cbook • numpy.lib._datasource • pandas._testing._io • pandas.io.common • scipy.misc.common • shutil • tarfile • zipfile

cPickle MissingModule

imports: cStringIO • copy_reg

imported by: pyqtgraph.multiprocess.processes • pyqtgraph.multiprocess.remoteproxy

cProfile SourceModule

imports: _lsprof • marshal • optparse • os • profile • pstats • runpy • sys

imported by: pyqtgraph.debug

cStringIO MissingModule

imports: copy_reg

imported by: PyQt5.uic.port_v2.string_io • cPickle

calendar SourceModule

imports: argparse • datetime • itertools • locale • sys

imported by: PIL.PdfParser • _strptime • dateutil.parser._parser • dateutil.parser.isoparser • dateutil.relativedelta • dateutil.rrule • email._parseaddr • http.cookiejar • ssl

certifi MissingModule

imported by: matplotlib

cffi MissingModule

imported by: PIL.Image • PIL.ImageTk • PIL.PyAccess • scipy._lib._ccallback • win32ctypes.core

cgi SourceModule

imports: collections.abc • email.message • email.parser • html • io • locale • os • re • sys • tempfile • traceback • urllib.parse • warnings

imported by: distutils.config

cmath (builtin module)

imported by: pandas

cmd SourceModule

imports: readline • string • sys

imported by: pdb • pstats

code SourceModule

imports: argparse • codeop • readline • sys • traceback

imported by: pdb

codecs SourceModule

imports: _codecs • builtins • encodings • sys

imported by: PIL.PdfParser • PyInstaller.lib.modulegraph.modulegraph • PyInstaller.utils.misc • _pickle • encodings • encodings.ascii • encodings.base64_codec • encodings.big5 • encodings.big5hkscs • encodings.bz2_codec • encodings.charmap • encodings.cp037 • encodings.cp1006 • encodings.cp1026 • encodings.cp1125 • encodings.cp1140 • encodings.cp1250 • encodings.cp1251 • encodings.cp1252 • encodings.cp1253 • encodings.cp1254 • encodings.cp1255 • encodings.cp1256 • encodings.cp1257 • encodings.cp1258 • encodings.cp273 • encodings.cp424 • encodings.cp437 • encodings.cp500 • encodings.cp65001 • encodings.cp720 • encodings.cp737 • encodings.cp775 • encodings.cp850 • encodings.cp852 • encodings.cp855 • encodings.cp856 • encodings.cp857 • encodings.cp858 • encodings.cp860 • encodings.cp861 • encodings.cp862 • encodings.cp863 • encodings.cp864 • encodings.cp865 • encodings.cp866 • encodings.cp869 • encodings.cp874 • encodings.cp875 • encodings.cp932 • encodings.cp949 • encodings.cp950 • encodings.euc_jis_2004 • encodings.euc_jisx0213 • encodings.euc_jp • encodings.euc_kr • encodings.gb18030 • encodings.gb2312 • encodings.gbk • encodings.hex_codec • encodings.hp_roman8 • encodings.hz • encodings.idna • encodings.iso2022_jp • encodings.iso2022_jp_1 • encodings.iso2022_jp_2 • encodings.iso2022_jp_2004 • encodings.iso2022_jp_3 • encodings.iso2022_jp_ext • encodings.iso2022_kr • encodings.iso8859_1 • encodings.iso8859_10 • encodings.iso8859_11 • encodings.iso8859_13 • encodings.iso8859_14 • encodings.iso8859_15 • encodings.iso8859_16 • encodings.iso8859_2 • encodings.iso8859_3 • encodings.iso8859_4 • encodings.iso8859_5 • encodings.iso8859_6 • encodings.iso8859_7 • encodings.iso8859_8 • encodings.iso8859_9 • encodings.johab • encodings.koi8_r • encodings.koi8_t • encodings.koi8_u • encodings.kz1048 • encodings.latin_1 • encodings.mac_arabic • encodings.mac_centeuro • encodings.mac_croatian • encodings.mac_cyrillic • encodings.mac_farsi • encodings.mac_greek • encodings.mac_iceland • encodings.mac_latin2 • encodings.mac_roman • encodings.mac_romanian • encodings.mac_turkish • encodings.mbcs • encodings.oem • encodings.palmos • encodings.ptcp154 • encodings.punycode • encodings.quopri_codec • encodings.raw_unicode_escape • encodings.rot_13 • encodings.shift_jis • encodings.shift_jis_2004 • encodings.shift_jisx0213 • encodings.tis_620 • encodings.undefined • encodings.unicode_escape • encodings.unicode_internal • encodings.utf_16 • encodings.utf_16_be • encodings.utf_16_le • encodings.utf_32 • encodings.utf_32_be • encodings.utf_32_le • encodings.utf_7 • encodings.utf_8 • encodings.utf_8_sig • encodings.uu_codec • encodings.zlib_codec • iAcc.py • json • lib2to3.pgen2.driver • lib2to3.pgen2.tokenize • pandas.core.strings.accessor • pandas.io.common • pandas.io.formats.xml • pandas.util._print_versions • pefile • pickle • plistlib • tokenize • xml.sax.saxutils

codeop SourceModule

imports: __future__

imported by: code

collections Package

imports: _collections • _collections_abc • _weakref • collections.Iterable • collections.Mapping • collections.MutableMapping • copy • heapq • itertools • keyword • operator • reprlib • sys • warnings

imported by: PIL.PdfParser • PIL.TiffTags • PIL.features • PyInstaller.__main__ • PyInstaller.depend.analysis • PyInstaller.depend.bindepend • PyInstaller.lib.modulegraph.modulegraph • PyInstaller.utils.hooks • PyInstaller.utils.hooks.conda • _pydecimal • altgraph.Graph • altgraph.GraphUtil • ast • asyncio.base_events • asyncio.base_subprocess • asyncio.locks • asyncio.queues • asyncio.selector_events • asyncio.sslproto • collections.abc • concurrent.futures._base • configparser • contextlib • csv • dateutil.tz._factories • dateutil.tz.tz • difflib • dis • doctest • email._header_value_parser • email.feedparser • enum • functools • iAcc.py • importlib_metadata • importlib_metadata._collections • inspect • lib2to3.btm_matcher • lib2to3.pgen2.grammar • lib2to3.refactor • matplotlib • matplotlib._mathtext • matplotlib._pylab_helpers • matplotlib.afm • matplotlib.artist • matplotlib.axes._base • matplotlib.backend_bases • matplotlib.category • matplotlib.cbook • matplotlib.dviread • matplotlib.mathtext • matplotlib.patches • matplotlib.projections.polar • matplotlib.textpath • mpl_toolkits.mplot3d.axes3d • multiprocessing.pool • multiprocessing.queues • numpy.core.overrides • numpy.core.records • numpy.testing._private.parameterized • packaging._manylinux • packaging.version • pandas._config.config • pandas._testing • pandas.core.aggregation • pandas.core.arrays.sparse.array • pandas.core.common • pandas.core.dtypes.inference • pandas.core.frame • pandas.core.generic • pandas.core.groupby.base • pandas.core.groupby.generic • pandas.core.groupby.ops • pandas.core.internals.construction • pandas.core.internals.managers • pandas.core.internals.ops • pandas.core.reshape.concat • pandas.core.sorting • pandas.core.tools.datetimes • pandas.core.window.common • pandas.io.common • pandas.io.excel._odswriter • pandas.io.formats.style_render • pandas.io.html • pandas.io.json._json • pandas.io.json._normalize • pandas.io.parsers.base_parser • pandas.io.parsers.python_parser • pandas.io.parsers.readers • pandas.io.sas.sas7bdat • pandas.io.sas.sas_xport • pandas.io.stata • pandas.plotting._matplotlib.boxplot • pandas.util.version • pefile • pkg_resources • pkg_resources._vendor.packaging.version • pkg_resources._vendor.pyparsing • pkgutil • platform • pprint • pydoc • pyparsing.util • pyqtgraph.configfile • pyqtgraph.examples.ExampleApp • pyqtgraph.flowchart.Flowchart • pyqtgraph.flowchart.Node • pyqtgraph.flowchart.NodeLibrary • pyqtgraph.functions • pyqtgraph.graphicsItems.DateAxisItem • pyqtgraph.graphicsItems.GradientEditorItem • pyqtgraph.graphicsItems.GraphicsItem • pyqtgraph.graphicsItems.ScatterPlotItem • pyqtgraph.ordereddict • pyqtgraph.parametertree.Parameter • pyqtgraph.parametertree.SystemSolver • pyqtgraph.parametertree.parameterTypes.list • pyqtgraph.widgets.ColorMapWidget • pyqtgraph.widgets.ComboBox • pyqtgraph.widgets.DataFilterWidget • pyqtgraph.widgets.DataTreeWidget • pyqtgraph.widgets.ScatterPlotWidget • pytz.lazy • queue • scipy._lib._pep440 • scipy._lib._util • scipy._lib.decorator • scipy.integrate._quad_vec • scipy.optimize._linprog_util • scipy.optimize._spectral • scipy.optimize.zeros • scipy.stats._binned_statistic • scipy.stats._common • scipy.stats._hypotests • scipy.stats._mannwhitneyu • scipy.stats.morestats • scipy.stats.mstats_basic • scipy.stats.stats • selectors • setuptools._vendor.packaging.version • setuptools._vendor.pyparsing • setuptools.command.egg_info • setuptools.config • setuptools.dist • setuptools.pep425tags • setuptools.py33compat • shlex • shutil • ssl • string • threading • tokenize • traceback • typing • typing_extensions • unittest.case • unittest.util • urllib.parse • xml.etree.ElementTree

collections.Iterable MissingModule

imported by: collections • pkg_resources._vendor.pyparsing • setuptools._vendor.pyparsing

collections.Mapping MissingModule

imported by: collections • pytz.lazy

collections.MutableMapping MissingModule

imported by: collections • pkg_resources._vendor.pyparsing • setuptools._vendor.pyparsing

collections.abc SourceModule

imports: _collections_abc • collections

imported by: PIL.Image • PIL.TiffImagePlugin • asyncio.base_events • asyncio.coroutines • cgi • configparser • http.client • iAcc.py • inspect • logging • matplotlib • matplotlib.axes._base • matplotlib.cbook • matplotlib.cm • matplotlib.colors • matplotlib.legend_handler • matplotlib.markers • matplotlib.spines • numpy.core._ufunc_config • numpy.lib.function_base • numpy.lib.npyio • numpy.testing._private.decorators • pandas.core.arrays.sparse.array • pandas.core.arrays.string_arrow • pandas.core.common • pandas.core.dtypes.inference • pandas.core.frame • pandas.core.groupby.generic • pandas.core.internals.construction • pandas.core.reshape.concat • pandas.core.strings.accessor • pandas.core.strings.base • pandas.core.strings.object_array • pandas.core.tools.datetimes • pandas.io.common • pandas.io.html • pandas.io.json._json • pandas.io.json._normalize • pandas.io.parsers.python_parser • pandas.io.parsers.readers • pandas.io.sas.sas7bdat • pandas.io.sas.sas_xport • pandas.io.stata • pkg_resources._vendor.pyparsing • pyparsing.core • pyparsing.results • pyqtgraph.colormap • pyqtgraph.graphicsItems.ImageItem • pyqtgraph.graphicsItems.PlotItem.PlotItem • pytz.lazy • scipy.linalg._decomp_cossin • scipy.ndimage._ni_support • scipy.ndimage.filters • scipy.stats._continuous_distns • selectors • setuptools._vendor.pyparsing • sqlite3.dbapi2 • tracemalloc • typing • typing_extensions • xml.etree.ElementTree

colorcet MissingModule

imported by: pyqtgraph.colormap

colorsys SourceModule

imported by: PIL.ImageColor

com MissingModule

imported by: pkg_resources._vendor.appdirs

concurrent Package

imported by: concurrent.futures

concurrent.futures Package

imports: concurrent • concurrent.futures._base • concurrent.futures.process • concurrent.futures.thread

imported by: asyncio.base_events • asyncio.futures • asyncio.tasks • concurrent.futures._base • concurrent.futures.process • concurrent.futures.thread • distutils.command.build_ext

concurrent.futures._base SourceModule

imports: collections • concurrent.futures • logging • threading • time

imported by: asyncio.base_futures • concurrent.futures • concurrent.futures.process • concurrent.futures.thread

concurrent.futures.process SourceModule

imports: atexit • concurrent.futures • concurrent.futures._base • functools • itertools • multiprocessing • multiprocessing.connection • multiprocessing.queues • os • queue • threading • traceback • weakref

imported by: concurrent.futures

concurrent.futures.thread SourceModule

imports: atexit • concurrent.futures • concurrent.futures._base • itertools • os • queue • threading • weakref

imported by: concurrent.futures

configparser SourceModule

imports: collections • collections.abc • functools • io • itertools • os • re • sys • warnings

imported by: configparser • distutils.config • distutils.dist • numpy.distutils.npy_pkg_config • numpy.distutils.system_info

configparser AliasNode

imports: configparser • setuptools.extern.six.moves

imported by: setuptools.command.easy_install • setuptools.command.setopt • setuptools.dist • setuptools.extern.six.moves • setuptools.package_index

contextlib SourceModule

imports: _collections_abc • abc • collections • functools • sys

imported by: _osx_support • _threading_local • dateutil.tz.tz • distutils.command.build_ext • getpass • importlib.util • importlib_metadata • matplotlib • matplotlib._api.deprecation • matplotlib.artist • matplotlib.axes._base • matplotlib.backend_bases • matplotlib.backends.backend_agg • matplotlib.backends.backend_webagg • matplotlib.backends.qt_compat • matplotlib.cbook • matplotlib.figure • matplotlib.patches • matplotlib.style.core • matplotlib.widgets • numpy.core._methods • numpy.core._ufunc_config • numpy.core.arrayprint • numpy.core.memmap • numpy.core.records • numpy.lib.histograms • numpy.lib.npyio • numpy.testing._private.utils • packaging._musllinux • pandas._config.config • pandas._config.localization • pandas._testing._warnings • pandas._testing.contexts • pandas.compat.pickle_compat • pandas.core.common • pandas.core.groupby.groupby • pandas.core.indexing • pandas.io.clipboard • pandas.io.formats.format • pandas.io.formats.style • pandas.io.pytables • pandas.io.sql • pandas.plotting._matplotlib.converter • pandas.plotting._misc • pandas.util._exceptions • plistlib • pyparsing.testing • pyqtgraph.debug • pyqtgraph.parametertree.parameterTypes.pen • pyqtgraph.widgets.BusyCursor • scipy._lib._util • scipy._lib.decorator • scipy.fft._pocketfft.helper • setuptools.archive_util • setuptools.command.easy_install • setuptools.command.sdist • setuptools.sandbox • typing • unittest.case • urllib.request • win32ctypes.pywin32.pywintypes • xml.etree.ElementTree • zipp

contextvars SourceModule

imports: _contextvars

imported by: _pydecimal • asyncio.events • asyncio.futures • asyncio.tasks

copy SourceModule

imports: copyreg • org • types • weakref

imported by: PIL.GifImagePlugin • PyInstaller.depend.analysis • PyInstaller.utils.hooks • _sre • argparse • collections • cycler • dataclasses • distutils.cygwinccompiler • email.generator • gettext • http.cookiejar • http.server • matplotlib.backends.qt_editor._formlayout • matplotlib.colorbar • matplotlib.colors • matplotlib.gridspec • matplotlib.path • matplotlib.transforms • matplotlib.widgets • numpy.distutils.ccompiler • numpy.distutils.command.build_src • numpy.distutils.misc_util • numpy.distutils.system_info • numpy.f2py.capi_maps • numpy.f2py.cfuncs • numpy.f2py.crackfortran • numpy.f2py.func2subr • numpy.f2py.rules • numpy.ma.core • pandas.compat.pickle_compat • pandas.core.indexes.base • pandas.core.indexes.multi • pandas.core.internals.concat • pandas.core.resample • pandas.core.reshape.merge • pandas.core.window.rolling • pandas.io.formats.style • pandas.io.json._normalize • pandas.io.parsers.python_parser • pandas.io.pytables • pefile • pkg_resources._vendor.pyparsing • pyparsing.core • pyqtgraph.graphicsItems.ViewBox.ViewBox • pyqtgraph.metaarray.MetaArray • pyqtgraph.parametertree.SystemSolver • scipy.integrate._quad_vec • scipy.integrate.odepack • scipy.optimize._linprog • scipy.optimize._shgo_lib.triangulation • scipy.signal.ltisys • scipy.sparse.linalg.dsolve.linsolve • scipy.stats._qmc • setuptools._vendor.pyparsing • tarfile • weakref • webbrowser • xml.dom.xmlbuilder • xml.etree.ElementInclude

copy_reg MissingModule

imported by: cPickle • cStringIO

copyreg SourceModule

imported by: _pickle • copy • iAcc.py • multiprocessing.reduction • numpy.core • pickle • re • scipy._lib._uarray._backend

csv SourceModule

imports: _csv • collections • io • re

imported by: importlib_metadata • pandas._testing.contexts • pandas.core.arrays.categorical • pandas.io.formats.csvs • pandas.io.formats.format • pandas.io.parsers.base_parser • pandas.io.parsers.python_parser • pandas.io.parsers.readers

ctypes Package

imports: _ctypes • ctypes._endian • ctypes.wintypes • os • struct • sys

imported by: ctypes._aix • ctypes._endian • ctypes.macholib • ctypes.util • ctypes.wintypes • dateutil.tz.win • matplotlib.backends.backend_qtagg • multiprocessing.sharedctypes • numpy._distributor_init • numpy.core._dtype_ctypes • numpy.core._internal • numpy.ctypeslib • numpy.distutils._shell_utils • packaging._manylinux • pandas.io.clipboard • pkg_resources._vendor.appdirs • pyqtgraph.util.colorama.win32 • scipy._distributor_init • scipy._lib._ccallback • scipy.stats._continuous_distns • serial.serialwin32 • serial.tools.list_ports_osx • serial.tools.list_ports_windows • serial.win32 • setuptools.glibc • setuptools.windows_support • uuid • win32ctypes.core.ctypes._authentication • win32ctypes.core.ctypes._common • win32ctypes.core.ctypes._resource • win32ctypes.core.ctypes._system_information • win32ctypes.core.ctypes._util

ctypes._aix SourceModule

imports: ctypes • os • re • subprocess • sys

imported by: ctypes.util

ctypes._endian SourceModule

imports: ctypes • sys

imported by: ctypes

ctypes.macholib Package

imports: ctypes

imported by: ctypes.macholib.dyld • ctypes.macholib.dylib • ctypes.macholib.framework

ctypes.macholib.dyld SourceModule

imports: ctypes.macholib • ctypes.macholib.dylib • ctypes.macholib.framework • itertools • os

imported by: ctypes.util

ctypes.macholib.dylib SourceModule

imports: ctypes.macholib • re

imported by: ctypes.macholib.dyld

ctypes.macholib.framework SourceModule

imports: ctypes.macholib • re

imported by: ctypes.macholib.dyld

ctypes.util SourceModule

imports: ctypes • ctypes._aix • ctypes.macholib.dyld • importlib.machinery • os • re • shutil • struct • subprocess • sys • tempfile

imported by: PyInstaller.compat • PyInstaller.depend.bindepend • PyInstaller.depend.utils • uuid

ctypes.wintypes SourceModule

imports: ctypes

imported by: ctypes • dateutil.tz.win • pandas.io.clipboard • pyqtgraph.util.colorama.win32 • serial.tools.list_ports_windows • serial.win32 • win32ctypes.core.ctypes._authentication • win32ctypes.core.ctypes._common • win32ctypes.core.ctypes._dll • win32ctypes.core.ctypes._nl_support • win32ctypes.core.ctypes._resource • win32ctypes.core.ctypes._system_information • win32ctypes.core.ctypes._time

cupy MissingModule

imported by: pyqtgraph.util.cupy_helper

curses Package

imports: _curses • curses • curses.has_key • os • sys

imported by: _curses • curses • curses.has_key • numpy.distutils.misc_util

curses.has_key SourceModule

imports: _curses • curses

imported by: curses

cycler SourceModule

imports: copy • functools • itertools • operator

imported by: matplotlib.pyplot • matplotlib.rcsetup

dataclasses SourceModule

imports: _thread • builtins • copy • functools • inspect • keyword • re • sys • types

imported by: matplotlib._text_helpers • matplotlib.font_manager • pandas.core.dtypes.inference • pandas.core.internals.construction • pandas.io.common • scipy.spatial.distance • scipy.stats._bootstrap • scipy.stats._hypotests • scipy.stats._mannwhitneyu • scipy.stats._page_trend_test • scipy.stats._relative_risk • scipy.stats.stats

datetime SourceModule

imports: _datetime • _strptime • math • sys • time

imported by: _strptime • calendar • dateutil.easter • dateutil.parser._parser • dateutil.parser.isoparser • dateutil.relativedelta • dateutil.rrule • dateutil.tz._common • dateutil.tz._factories • dateutil.tz.tz • dateutil.tz.win • email.utils • http.cookiejar • http.server • matplotlib.axis • matplotlib.backends.backend_webagg_core • matplotlib.backends.qt_editor._formlayout • matplotlib.dates • matplotlib.pylab • pandas • pandas._testing • pandas._typing • pandas.core.arrays.datetimelike • pandas.core.arrays.datetimes • pandas.core.arrays.numeric • pandas.core.arrays.period • pandas.core.arrays.timedeltas • pandas.core.computation.ops • pandas.core.computation.scope • pandas.core.dtypes.cast • pandas.core.dtypes.dtypes • pandas.core.frame • pandas.core.generic • pandas.core.groupby.groupby • pandas.core.indexes.base • pandas.core.indexes.datetimelike • pandas.core.indexes.datetimes • pandas.core.indexes.period • pandas.core.indexes.range • pandas.core.ops.array_ops • pandas.core.resample • pandas.core.reshape.merge • pandas.core.tools.datetimes • pandas.core.tools.times • pandas.core.window.ewm • pandas.core.window.indexers • pandas.core.window.rolling • pandas.io.excel._base • pandas.io.excel._odswriter • pandas.io.excel._xlrd • pandas.io.parsers.base_parser • pandas.io.pytables • pandas.io.sas.sas7bdat • pandas.io.sas.sas_xport • pandas.io.sql • pandas.io.stata • pandas.plotting._matplotlib.converter • pkg_resources._vendor.pyparsing • plistlib • pyparsing.common • pyqtgraph.configfile • pyqtgraph.graphicsItems.DateAxisItem • pytz • pytz.tzfile • pytz.tzinfo • setuptools._vendor.pyparsing • sqlite3.dbapi2 • xmlrpc.client

dateutil Package

imports: dateutil • dateutil._version • dateutil.easter • dateutil.relativedelta • dateutil.rrule • dateutil.tz

imported by: dateutil • dateutil._common • dateutil._version • dateutil.easter • dateutil.parser • dateutil.parser._parser • dateutil.parser.isoparser • dateutil.relativedelta • dateutil.rrule • dateutil.tz • dateutil.tz.tz • dateutil.zoneinfo

dateutil._common SourceModule

imports: dateutil

imported by: dateutil.relativedelta • dateutil.rrule

dateutil._version SourceModule

imports: dateutil

imported by: dateutil

dateutil.easter SourceModule

imports: datetime • dateutil

imported by: dateutil • dateutil.rrule

dateutil.parser Package

imports: dateutil • dateutil.parser._parser • dateutil.parser.isoparser • functools • warnings

imported by: dateutil.parser._parser • dateutil.parser.isoparser • dateutil.rrule • dateutil.tz.tz • matplotlib.category • matplotlib.dates • pandas.core.indexes.datetimes

dateutil.parser._parser SourceModule

imports: __future__ • calendar • datetime • dateutil • dateutil.parser • dateutil.relativedelta • dateutil.tz • decimal • io • re • six • string • time • warnings

imported by: dateutil.parser • dateutil.tz.tz

dateutil.parser.isoparser SourceModule

imports: calendar • datetime • dateutil • dateutil.parser • dateutil.tz • functools • re • six

imported by: dateutil.parser

dateutil.relativedelta SourceModule

imports: calendar • datetime • dateutil • dateutil._common • math • operator • six • warnings

imported by: dateutil • dateutil.parser._parser • dateutil.tz.tz • matplotlib.dates • pandas.io.stata • pandas.plotting._matplotlib.converter

dateutil.rrule SourceModule

imports: _thread • calendar • datetime • dateutil • dateutil._common • dateutil.easter • dateutil.parser • dateutil.tz • fractions • functools • heapq • itertools • math • re • six • six.moves • six.moves.range • sys • warnings

imported by: dateutil • dateutil.tz.tz • matplotlib.dates

dateutil.tz Package

imports: dateutil • dateutil.tz.tz • dateutil.tz.tzfile

imported by: dateutil • dateutil.parser._parser • dateutil.parser.isoparser • dateutil.rrule • dateutil.tz._common • dateutil.tz._factories • dateutil.tz.tz • dateutil.tz.win • dateutil.zoneinfo • matplotlib.axis • matplotlib.dates

dateutil.tz._common SourceModule

imports: datetime • dateutil.tz • functools • six

imported by: dateutil.tz.tz • dateutil.tz.win

dateutil.tz._factories SourceModule

imports: _thread • collections • datetime • dateutil.tz • six.moves • weakref

imported by: dateutil.tz.tz

dateutil.tz.tz SourceModule

imports: _thread • bisect • collections • contextlib • datetime • dateutil • dateutil.parser • dateutil.parser._parser • dateutil.relativedelta • dateutil.rrule • dateutil.tz • dateutil.tz._common • dateutil.tz._factories • dateutil.tz.win • dateutil.zoneinfo • os • six • six.moves • struct • sys • time • warnings • weakref

imported by: dateutil.tz

dateutil.tz.tzfile MissingModule

imported by: dateutil.tz • dateutil.zoneinfo

dateutil.tz.win SourceModule

imports: ctypes • ctypes.wintypes • datetime • dateutil.tz • dateutil.tz._common • six • six.moves • struct • winreg

imported by: dateutil.tz.tz

dateutil.zoneinfo Package

imports: dateutil • dateutil.tz • dateutil.tz.tzfile • io • json • pkgutil • tarfile • warnings

imported by: dateutil.tz.tz

decimal SourceModule

imports: _decimal • _pydecimal

imported by: dateutil.parser._parser • fractions • matplotlib.units • pandas._testing • pandas.core.dtypes.missing • pandas.io.formats.format • pyqtgraph.functions • pyqtgraph.widgets.SpinBox • xmlrpc.client

defusedxml MissingModule

imported by: PIL.Image

difflib SourceModule

imports: collections • difflib • heapq • re

imported by: difflib • doctest • numpy.testing._private.utils • unittest.case

dis SourceModule

imports: argparse • collections • io • opcode • sys • types

imported by: PyInstaller.depend.bytecode • PyInstaller.lib.modulegraph._compat • inspect • pdb • setuptools.py33compat

distutils Package

imports: distutils.archive_util • distutils.ccompiler • distutils.log • distutils.sysconfig • sys

imported by: _osx_support • distutils._msvccompiler • distutils.archive_util • distutils.ccompiler • distutils.cmd • distutils.command • distutils.command.bdist_rpm • distutils.command.build_clib • distutils.command.build_ext • distutils.command.build_py • distutils.command.build_scripts • distutils.command.config • distutils.command.install • distutils.command.install_scripts • distutils.command.sdist • distutils.config • distutils.core • distutils.cygwinccompiler • distutils.debug • distutils.dep_util • distutils.dir_util • distutils.dist • distutils.errors • distutils.extension • distutils.fancy_getopt • distutils.file_util • distutils.filelist • distutils.log • distutils.msvc9compiler • distutils.msvccompiler • distutils.spawn • distutils.sysconfig • distutils.text_file • distutils.unixccompiler • distutils.util • distutils.version • distutils.versionpredicate • setuptools.command.bdist_egg • setuptools.command.develop • setuptools.command.easy_install • setuptools.command.egg_info • setuptools.command.install_scripts • setuptools.command.sdist • setuptools.command.setopt • setuptools.namespaces • setuptools.package_index • setuptools.pep425tags

distutils._msvccompiler SourceModule

imports: distutils • distutils.ccompiler • distutils.errors • distutils.log • distutils.util • glob • itertools • json • os • shutil • stat • subprocess • winreg

imported by: distutils.command.build_ext

distutils.archive_util SourceModule

imports: distutils • distutils.dir_util • distutils.errors • distutils.log • distutils.spawn • grp • os • pwd • sys • tarfile • warnings • zipfile

imported by: distutils • distutils.cmd • distutils.command.sdist

distutils.ccompiler SourceModule

imports: distutils • distutils.debug • distutils.dep_util • distutils.dir_util • distutils.errors • distutils.fancy_getopt • distutils.file_util • distutils.log • distutils.spawn • distutils.util • os • re • sys • tempfile

imported by: distutils • distutils._msvccompiler • distutils.command.build • distutils.command.build_clib • distutils.command.build_ext • distutils.command.config • distutils.cygwinccompiler • distutils.msvc9compiler • distutils.msvccompiler • distutils.unixccompiler

distutils.cmd SourceModule

imports: distutils • distutils.archive_util • distutils.debug • distutils.dep_util • distutils.dir_util • distutils.dist • distutils.errors • distutils.fancy_getopt • distutils.file_util • distutils.log • distutils.spawn • distutils.util • os • re • sys

imported by: distutils.config • distutils.core • distutils.dist • setuptools.dist

distutils.command Package

imports: distutils

imported by: distutils.command.bdist • distutils.command.bdist_rpm • distutils.command.build • distutils.command.build_clib • distutils.command.build_ext • distutils.command.build_py • distutils.command.build_scripts • distutils.command.config • distutils.command.install • distutils.command.install_data • distutils.command.install_headers • distutils.command.install_scripts • distutils.command.sdist • distutils.dist • setuptools.command.py36compat

distutils.command.bdist SourceModule

imports: distutils.command • distutils.core • distutils.errors • distutils.fancy_getopt • distutils.util • os

imported by: setuptools.command

distutils.command.build_ext SourceModule

imports: concurrent.futures • contextlib • distutils • distutils._msvccompiler • distutils.ccompiler • distutils.command • distutils.core • distutils.dep_util • distutils.errors • distutils.extension • distutils.log • distutils.sysconfig • distutils.util • os • re • site • sys

imported by: setuptools

distutils.command.build_scripts SourceModule

imports: distutils • distutils.command • distutils.core • distutils.dep_util • distutils.log • distutils.sysconfig • distutils.util • os • re • stat • tokenize

imported by: setuptools.command.easy_install

distutils.command.install SourceModule

imports: distutils • distutils.command • distutils.core • distutils.debug • distutils.errors • distutils.fancy_getopt • distutils.file_util • distutils.log • distutils.sysconfig • distutils.util • os • pprint • site • sys

imported by: setuptools.command.easy_install • setuptools.command.install

distutils.command.install_scripts SourceModule

imports: distutils • distutils.command • distutils.core • distutils.log • os • stat

imported by: setuptools.command.install_scripts

distutils.command.sdist SourceModule

imports: distutils • distutils.archive_util • distutils.command • distutils.core • distutils.dir_util • distutils.errors • distutils.fancy_getopt • distutils.file_util • distutils.filelist • distutils.log • distutils.text_file • distutils.util • glob • os • sys • warnings

imported by: setuptools.command.py36compat • setuptools.command.sdist

distutils.config SourceModule

imports: cgi • configparser • distutils • distutils.cmd • os

imported by: distutils.core

distutils.core SourceModule

imports: distutils • distutils.cmd • distutils.config • distutils.debug • distutils.dist • distutils.errors • distutils.extension • os • sys

imported by: distutils.command.bdist • distutils.command.bdist_rpm • distutils.command.build • distutils.command.build_clib • distutils.command.build_ext • distutils.command.build_py • distutils.command.build_scripts • distutils.command.config • distutils.command.install • distutils.command.install_data • distutils.command.install_headers • distutils.command.install_scripts • distutils.command.sdist • distutils.dist • setuptools • setuptools.command.easy_install • setuptools.dist • setuptools.extension

distutils.debug SourceModule

imports: distutils • os

imported by: distutils.ccompiler • distutils.cmd • distutils.command.bdist_rpm • distutils.command.install • distutils.core • distutils.dist • distutils.filelist • distutils.spawn • setuptools.dist

distutils.dep_util SourceModule

imports: distutils • distutils.errors • os • stat

imported by: distutils.ccompiler • distutils.cmd • distutils.command.build_ext • distutils.command.build_scripts • distutils.file_util • distutils.unixccompiler • distutils.util

distutils.dir_util SourceModule

imports: distutils • distutils.errors • distutils.file_util • distutils.log • errno • os

imported by: distutils.archive_util • distutils.ccompiler • distutils.cmd • distutils.command.sdist • distutils.util • setuptools.command.bdist_egg • setuptools.command.easy_install

distutils.dist SourceModule

imports: configparser • distutils • distutils.cmd • distutils.command • distutils.core • distutils.debug • distutils.errors • distutils.fancy_getopt • distutils.log • distutils.util • distutils.versionpredicate • email • os • pprint • re • sys • warnings

imported by: distutils.cmd • distutils.core • setuptools.dist

distutils.errors SourceModule

imports: distutils

imported by: distutils._msvccompiler • distutils.archive_util • distutils.ccompiler • distutils.cmd • distutils.command.bdist • distutils.command.bdist_rpm • distutils.command.build • distutils.command.build_clib • distutils.command.build_ext • distutils.command.build_py • distutils.command.config • distutils.command.install • distutils.command.sdist • distutils.core • distutils.cygwinccompiler • distutils.dep_util • distutils.dir_util • distutils.dist • distutils.fancy_getopt • distutils.file_util • distutils.filelist • distutils.msvc9compiler • distutils.msvccompiler • distutils.spawn • distutils.sysconfig • distutils.unixccompiler • distutils.util • setuptools • setuptools.archive_util • setuptools.command.bdist_egg • setuptools.command.develop • setuptools.command.easy_install • setuptools.command.egg_info • setuptools.command.install • setuptools.command.setopt • setuptools.config • setuptools.dist • setuptools.extension • setuptools.msvc • setuptools.package_index • setuptools.sandbox

distutils.extension SourceModule

imports: distutils • distutils.sysconfig • distutils.text_file • distutils.util • os • warnings

imported by: distutils.command.build_ext • distutils.core • setuptools.extension

distutils.fancy_getopt SourceModule

imports: distutils • distutils.errors • getopt • re • string • sys

imported by: distutils.ccompiler • distutils.cmd • distutils.command.bdist • distutils.command.install • distutils.command.sdist • distutils.dist • setuptools.dist

distutils.file_util SourceModule

imports: distutils • distutils.dep_util • distutils.errors • distutils.log • errno • ntpath • os • stat

imported by: distutils.ccompiler • distutils.cmd • distutils.command.bdist_rpm • distutils.command.install • distutils.command.sdist • distutils.cygwinccompiler • distutils.dir_util • distutils.util • setuptools.command.easy_install

distutils.filelist SourceModule

imports: distutils • distutils.debug • distutils.errors • distutils.log • distutils.util • fnmatch • functools • os • re

imported by: distutils.command.sdist • distutils.util • setuptools • setuptools.command.egg_info • setuptools.monkey

distutils.log SourceModule

imports: distutils • sys

imported by: _osx_support • distutils • distutils._msvccompiler • distutils.archive_util • distutils.ccompiler • distutils.cmd • distutils.command.bdist_rpm • distutils.command.build_clib • distutils.command.build_ext • distutils.command.build_py • distutils.command.build_scripts • distutils.command.config • distutils.command.install • distutils.command.install_scripts • distutils.command.sdist • distutils.cygwinccompiler • distutils.dir_util • distutils.dist • distutils.file_util • distutils.filelist • distutils.msvc9compiler • distutils.msvccompiler • distutils.spawn • distutils.unixccompiler • distutils.util • setuptools.command.bdist_egg • setuptools.command.develop • setuptools.command.easy_install • setuptools.command.egg_info • setuptools.command.install_scripts • setuptools.command.sdist • setuptools.command.setopt • setuptools.dist • setuptools.namespaces • setuptools.package_index • setuptools.pep425tags

distutils.msvc9compiler SourceModule

imports: distutils • distutils.ccompiler • distutils.errors • distutils.log • distutils.util • os • re • subprocess • sys • winreg

imported by: distutils.msvccompiler • setuptools.msvc

distutils.spawn SourceModule

imports: distutils • distutils.debug • distutils.errors • distutils.log • distutils.sysconfig • os • sys

imported by: PyInstaller.depend.utils • distutils.archive_util • distutils.ccompiler • distutils.cmd • distutils.cygwinccompiler • distutils.util • setuptools.command.easy_install

distutils.sysconfig SourceModule

imports: _imp • _osx_support • distutils • distutils.errors • distutils.text_file • os • re • sys • warnings

imported by: PyInstaller.depend.bindepend • distutils • distutils.command.bdist_rpm • distutils.command.build_clib • distutils.command.build_ext • distutils.command.build_scripts • distutils.command.config • distutils.command.install • distutils.cygwinccompiler • distutils.extension • distutils.spawn • distutils.unixccompiler • distutils.util • setuptools.command.bdist_egg

distutils.text_file SourceModule

imports: distutils • io • sys

imported by: distutils.command.sdist • distutils.extension • distutils.sysconfig

distutils.util SourceModule

imports: _osx_support • distutils • distutils.dep_util • distutils.dir_util • distutils.errors • distutils.file_util • distutils.filelist • distutils.log • distutils.spawn • distutils.sysconfig • importlib.util • os • pwd • py_compile • re • string • subprocess • sys • tempfile

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

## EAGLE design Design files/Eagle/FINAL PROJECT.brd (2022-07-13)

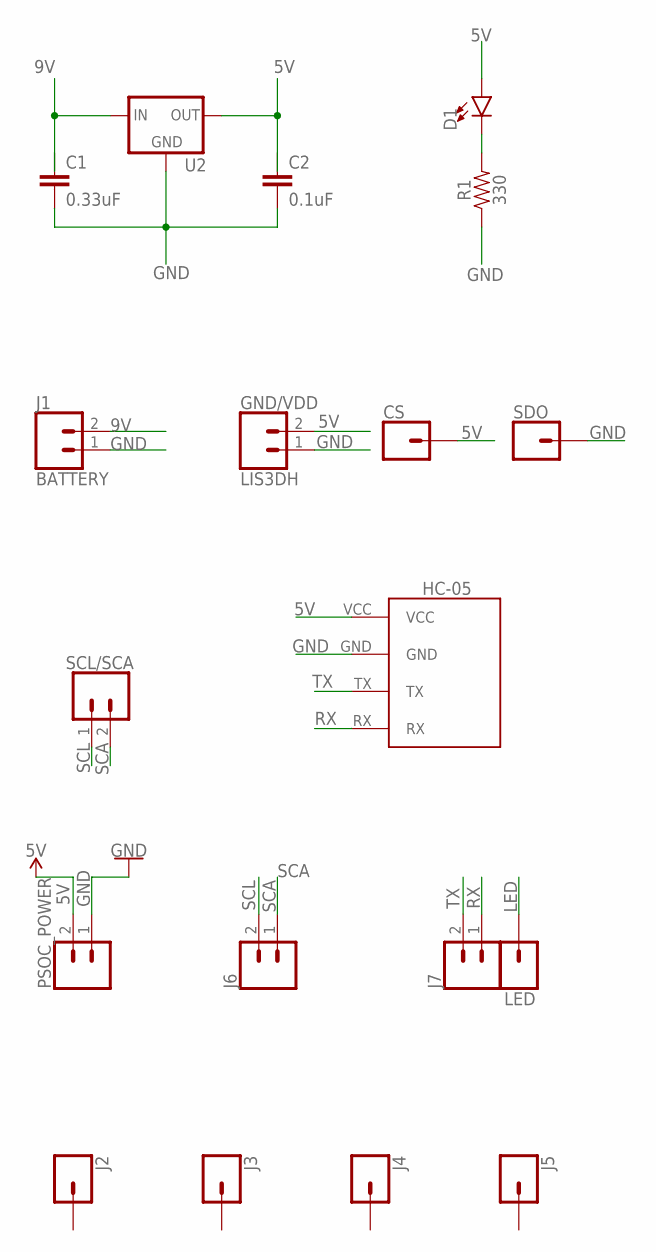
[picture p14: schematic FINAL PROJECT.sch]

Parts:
C1: 0.33uF; CAP-PTH-SMALL-KIT
C2: 0.1uF; CAP-PTH-SMALL-KIT
CS: CONN_01; 1X01
D1: LED3MM; LED_3MM
GND/VDD: LIS3DH; 1X02
HC-05: BLUETOOTH_BOARD; BT_BOARD_FOOTPRINT
J1: BATTERY; 1X02
J2, J3, J4, J5: CONN_01; 1X01
J6, J7: CONN_02; 1X02
LED: CONN_01; 1X01
PSOC_POWER: CONN_02; 1X02
R1: 330; AXIAL-0.3
SCL/SCA: CONN_02; 1X02
SDO: CONN_01; 1X01
U2: V_REG_78XX-TO-220; TO-220-ALT

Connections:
5V: C2.1, CS.1, D1.A, GND/VDD.2, HC-05.VCC, PSOC_POWER.2, U2.OUT
9V: C1.1, J1.2, U2.IN
GND: C1.2, C2.2, GND/VDD.1, HC-05.GND, J1.1, PSOC_POWER.1, R1.P$1 (1), SDO.1, U2.GND
LED: LED.1
unnamed: D1.K (C), R1.P$2 (2)
RX: HC-05.RX, J7.1
SCA: J6.1, SCL/SCA.2
SCL: J6.2, SCL/SCA.1
TX: HC-05.TX, J7.2

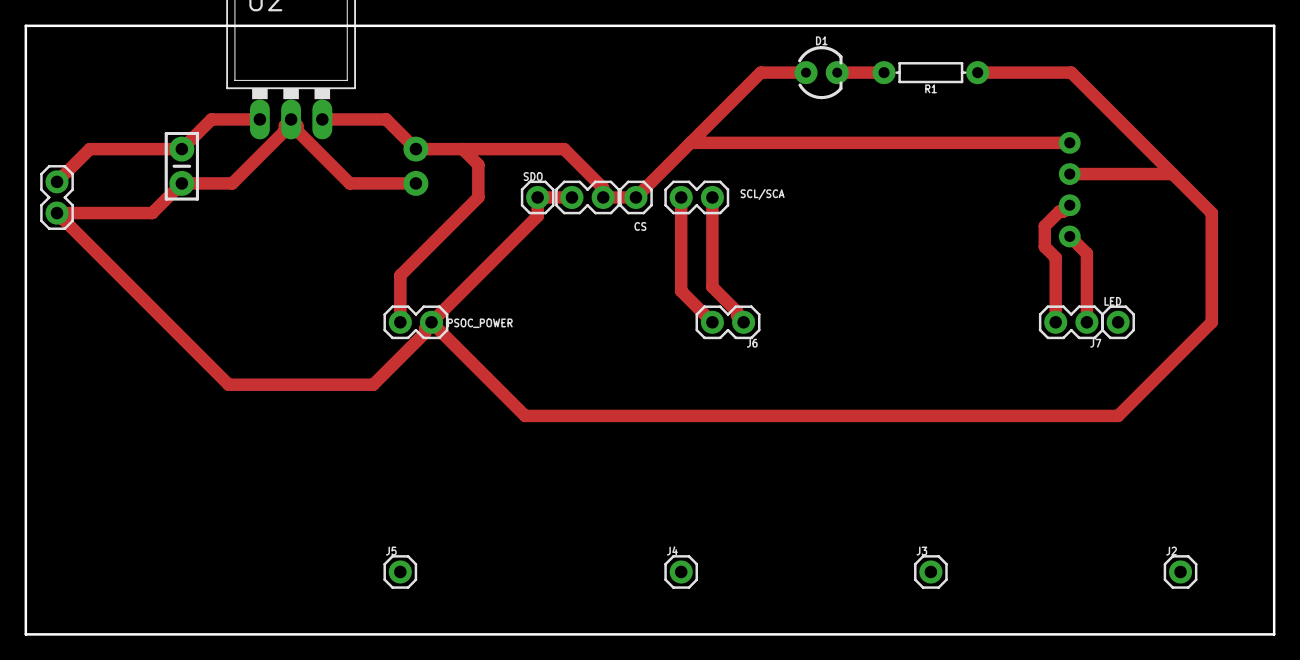
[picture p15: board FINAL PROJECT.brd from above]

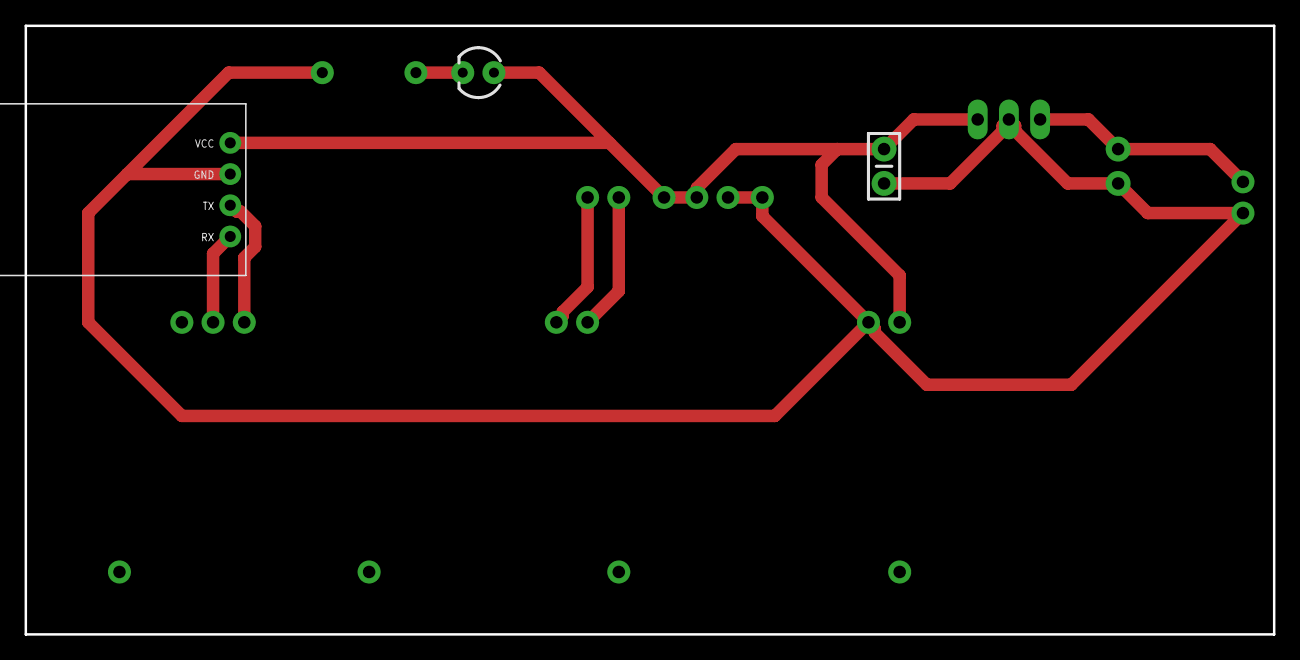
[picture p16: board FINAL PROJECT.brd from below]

Board: 2 copper layers, 101.6 x 49.5 mm, 19 parts (2 on the bottom side), 8 nets.

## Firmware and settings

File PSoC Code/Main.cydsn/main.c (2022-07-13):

#include <stdio.h>
#include "project.h"
#include "I2C_Interface.h"
#include "LIS3DH.h"
#include "InterruptRoutines.h"
#include "InterruptRoutinesBT.h"
#include "EEPROM_Custom.h"
#include "Defines.h"

// Set this to 1 to send byte data for the Bridge Control Panel
// Otherwise set it to 0 to send temperature data as int16_t
#define USE_BRIDGECONTROLPANEL  0
uint8_t ovrnReady;
uint8_t emptyBit;
uint8_t reg;
ErrorCode error;

char message[50] = {'\0'};

int main(void)
{
    CyGlobalIntEnable; /* Enable global interrupts. */

    /* Place your initialization/startup code here (e.g. MyInst_Start()) */
    I2C_Peripheral_Start();
    //The user can comment the UART that doesn't use, depending on which is the used one, USB/BT
    UART_BT_Start();
    isr_RX_BT_StartEx(Custom_ISR_RX_BT);
    //UART_Start();
    //isr_RX_StartEx(Custom_ISR_RX);
  
    //EEPROM_Custom_Start();
    
    CyDelay(5); //"The boot procedure is complete about 5 ms after device power-up."
    
    printHeader();
    
    /******************************************/
    /*            I2C Reading                 */
    /******************************************/
          
    /*      I2C Master Read - WHOAMI Register       */
    uint8_t whoami_reg=0x00;
    readReg(whoami_reg,LIS3DH_WHO_AM_I_REG_ADDR);
    
    
    /*      I2C Master Read - STATUS Register       */
    //The PutString commands can be decommented to use them for debugging
    //UART_PutString("\r\nStatus reg \r\n");
    //UART_BT_PutString("\r\nStatus reg \r\n");
    uint8_t status_reg=0x00;
    readReg(status_reg,LIS3DH_STATUS_REG);

    
    /*      I2C Master Read - CTRL Register 1       */
    //UART_PutString("\r\nCTRL reg1 \r\n");
    //UART_BT_PutString("\r\nCTRL reg1 \r\n");
    uint8_t control_reg=0x00;
    readReg(control_reg, LIS3DH_CTRL_REG1);

    /*      I2C Master Read - CTRL Register 3      */
    //UART_PutString("\r\nCTRL reg3 \r\n");
    //UART_BT_PutString("\r\nCTRL reg3 \r\n");
    uint8_t control_reg_3=0x00;
    readReg(control_reg_3, LIS3DH_CTRL_REG3);
    
    /*      I2C Master Read - CTRL Register 4      */
    //UART_PutString("\r\nCTRL reg4 \r\n");
    //UART_BT_PutString("\r\nCTRL reg4 \r\n");
    uint8_t control_reg_4=0x00;
    readReg(control_reg_4, LIS3DH_CTRL_REG4);
    
    /*      I2C Master Read - CTRL Register 5       */
    //UART_PutString("\r\nCTRL reg5 \r\n");
    //UART_BT_PutString("\r\nCTRL reg5 \r\n");
    uint8_t control_reg_5=0x00;
    readReg(control_reg_5, LIS3DH_CTRL_REG5);

    /*      I2C Master Read - FIFO CTRL Register     */
    //UART_PutString("\r\nFIFO REG \r\n");
    //UART_BT_PutString("\r\nFIFO REG \r\n");
    uint8_t FIFO_control_reg=0x00;
    readReg(FIFO_control_reg, LIS3DH_FIFO_CTRL_REG);
   
    
    /******************************************/
    /*       I2C Writing CTRL REG1            */
    /******************************************/
    
    //UART_PutString("\r\nSetting ctrl reg1 \r\n");
    //UART_BT_PutString("\r\nSetting ctrl reg1 \r\n");
    
    if (control_reg != LIS3DH_NORMAL_MODE_CTRL_REG1)
    {
        control_reg = LIS3DH_NORMAL_MODE_CTRL_REG1;
        
        setReg(control_reg,LIS3DH_CTRL_REG1);
    }
    
    /******************************************/
    /*     I2C Reading CTRL REG1 again        */
    /******************************************/
    
    //readReg(control_reg, LIS3DH_CTRL_REG1);
    
    /******************************************/
    /*       I2C Writing CTRL REG5            */
    /******************************************/
    

    if (control_reg_5 != LIS3DH_CTRL_REG5_FIFO_ON)
    {
        control_reg_5 = LIS3DH_CTRL_REG5_FIFO_ON;
        
        setReg(control_reg_5,LIS3DH_CTRL_REG5);

    }
    
    /******************************************/
    /*       I2C Writing CTRL REG3            */
    /******************************************/
 
    
    if (control_reg_3 != LIS3DH_CTRL_REG3_INT)
    {
        control_reg_3 = LIS3DH_CTRL_REG3_INT;
        
        setReg(control_reg_3,LIS3DH_CTRL_REG3);

    }
    
    /******************************************/
    /*     I2C Reading CTRL REG3 again        */
    /******************************************/
    
    readReg(control_reg_3, LIS3DH_CTRL_REG3);
    
    /******************************************/
    /*       I2C Writing FIFO CTRL REG        */
    /******************************************/
    if (FIFO_control_reg != LIS3DH_FIFO_ON)
    {
        FIFO_control_reg = LIS3DH_FIFO_ON;
        
        setReg(FIFO_control_reg,LIS3DH_FIFO_CTRL_REG);
    }
    
    /*      I2C Master Read - CTRL Register 5       */
    
    readReg(control_reg_5, LIS3DH_CTRL_REG5);
    
    /*      I2C Master Read - FIFO CTRL Register     */

    readReg(FIFO_control_reg, LIS3DH_FIFO_CTRL_REG);
   
    
    int16 regCount = 192;
    uint8_t data[192];
    uint8_t fifoFull;
    int16 xData[32];
    int16 yData[32];
    int16 zData[32];
    uint8_t dataSend[194];

    uint8_t regSetting;
    int16 arrayToSend[98];

    status=0;
    
    //UART_PutString("\r\nConfiguration complete\r\n");
    //UART_BT_PutString("\r\nConfiguration complete\r\n");
    
    regSetting=0x00;
    error = I2C_Peripheral_WriteRegister(LIS3DH_DEVICE_ADDRESS,LIS3DH_FIFO_CTRL_REG,regSetting);
    regSetting=0x40;
    error = I2C_Peripheral_WriteRegister(LIS3DH_DEVICE_ADDRESS,LIS3DH_FIFO_CTRL_REG,regSetting);
    
    for(;;)
    {
        switch (status)
        {
            case INITIALIZATION:
            
                // retrieve from EEPROM memory
                FS = EEPROM_retrieve_FS();
                So[0] = EEPROM_retrieve_So_lsb();
                So[1] = EEPROM_retrieve_So_msb();
                
                // read registers 
                readReg(control_reg_4, LIS3DH_CTRL_REG4);   //for both So[1] and FS[1:0]
                readReg(control_reg, LIS3DH_CTRL_REG1);     //for So[0]
     
                //writes FS in register CTRL_REG_4[5:4]
                setReg(((FS<<4)|control_reg_4), LIS3DH_CTRL_REG4);   //CTRL_REG4[5:4] contain FS
                
                // writes So[1:0] bits in reg1[3] and reg4[3]
                setReg(((So[0]<<3)|control_reg_4), LIS3DH_CTRL_REG4);   //lsb in CTRL_REG_4[3]
                setReg(((So[1]<<3)|control_reg), LIS3DH_CTRL_REG1);     //msb in CTRL_REG_1[3]
                
                //UART_PutString("\r\nFull Scale and Sensitivity settings retrieved and set\r\n");
                //UART_BT_PutString("\r\nFull Scale and Sensitivity settings retrieved and set\r\n");
                
                status = 0;
   
                break;
            
            case READING:
            
                CyDelay(500); //to get stable data
                //Read the FIFO status register and save the value in fifoFull
                error=I2C_Peripheral_ReadRegister(LIS3DH_DEVICE_ADDRESS, LIS3DH_FIFO_SRC_REG, &fifoFull); 
                //sprintf(message,"\r\novrn value: %d \r\n",(fifoFull & 0x40)>>6);
                //UART_PutString(message);
               
                if(error == NO_ERROR && (fifoFull & 0x40)>>6)   //if the FIFO register is full, the data is saved in the array to send
                {
                    I2C_Peripheral_ReadRegisterMulti(LIS3DH_DEVICE_ADDRESS,LIS3DH_OUT_X_L,regCount,data);
                    //UART_PutString("Data ready\n");
                    for(int i = 0; i<32;i++)
                    {
                        xData[i] = (int16) (data[i*6] | (data[i*6+1]<<8))>>6;
                        yData[i] = (int16) (data[i*6+2] | (data[i*6+3]<<8))>>6;
                        zData[i] = (int16) (data[i*6+4] | (data[i*6+5]<<8))>>6;
                    }
                    dataSend[0]=0x0A;
                    dataSend[193]=0x0B;
                    
                    for(int i=1;i<193;i++)
                    {
                        dataSend[i]=data[i-1];
                    }
                    
                    
                    //UART_PutArray(dataSend,194);
                    UART_BT_PutArray(dataSend, 194); //send data via BT
                    
                    //reset the FIFO register, so that it can acquire the new data
                    regSetting=0x00;
                    error = I2C_Peripheral_WriteRegister(LIS3DH_DEVICE_ADDRESS,LIS3DH_FIFO_CTRL_REG,regSetting);
                    regSetting=0x40;
                    error = I2C_Peripheral_WriteRegister(LIS3DH_DEVICE_ADDRESS,LIS3DH_FIFO_CTRL_REG,regSetting);
                }
                
                break;
                
            case TURNOFF: //save status
                
                EEPROM_save_status(FS, So);
//                EEPROM_Stop();
//                I2C_Peripheral_Stop();
//                UART_BT_Stop();
//                UART_Stop();
                //UART_BT_PutString("turn off device");
                //UART_PutString("turn off device");
                status = 0;
                
                break;
                
            default:
                break;
                
        }       
        // at any cycle check if there were changes from GUI in the FS and So registers and save in EEPROM
        
        if ((flag_FS == 1)||(flag_So == 1)) // FS value stored in FS
        {
            // save in EEPROM
            EEPROM_save_status(FS, So);
            
            // read again registers values
            readReg(control_reg, LIS3DH_CTRL_REG1);
            readReg(control_reg_4, LIS3DH_CTRL_REG4);
            
            // set necessary bits to 0
            control_reg = control_reg & 0b11000111; 
            control_reg_4 = control_reg_4 & 0b11110111;
            
            // write necessary values in registers
            setReg(((FS<<4)|control_reg_4), LIS3DH_CTRL_REG4);  
            setReg(((So[0]<<3)|control_reg_4), LIS3DH_CTRL_REG4); 
            setReg(((So[1]<<3)|control_reg), LIS3DH_CTRL_REG1); 
            
            flag_FS = 0;
            flag_So = 0;
        }
    }
}

/* [] END OF FILE */

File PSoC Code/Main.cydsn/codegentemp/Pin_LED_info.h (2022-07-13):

/*******************************************************************************
* File Name: Pin_LED_info.h  
* Version 2.20
*
* Description:
*  This file contains Pin function prototypes and register defines
*
* Note:
*
********************************************************************************
* Copyright 2008-2015, Cypress Semiconductor Corporation.  All rights reserved.
* You may use this file only in accordance with the license, terms, conditions, 
* disclaimers, and limitations in the end user license agreement accompanying 
* the software package with which this file was provided.
*******************************************************************************/

#if !defined(CY_PINS_Pin_LED_info_H) /* Pins Pin_LED_info_H */
#define CY_PINS_Pin_LED_info_H

#include "cytypes.h"
#include "cyfitter.h"
#include "cypins.h"
#include "Pin_LED_info_aliases.h"

/* APIs are not generated for P15[7:6] */
#if !(CY_PSOC5A &&\
	 Pin_LED_info__PORT == 15 && ((Pin_LED_info__MASK & 0xC0) != 0))


/***************************************
*        Function Prototypes             
***************************************/    

/**
* \addtogroup group_general
* @{
*/
void    Pin_LED_info_Write(uint8 value);
void    Pin_LED_info_SetDriveMode(uint8 mode);
uint8   Pin_LED_info_ReadDataReg(void);
uint8   Pin_LED_info_Read(void);
void    Pin_LED_info_SetInterruptMode(uint16 position, uint16 mode);
uint8   Pin_LED_info_ClearInterrupt(void);
/** @} general */

/***************************************
*           API Constants        
***************************************/
/**
* \addtogroup group_constants
* @{
*/
    /** \addtogroup driveMode Drive mode constants
     * \brief Constants to be passed as "mode" parameter in the Pin_LED_info_SetDriveMode() function.
     *  @{
     */
        #define Pin_LED_info_DM_ALG_HIZ         PIN_DM_ALG_HIZ
        #define Pin_LED_info_DM_DIG_HIZ         PIN_DM_DIG_HIZ
        #define Pin_LED_info_DM_RES_UP          PIN_DM_RES_UP
        #define Pin_LED_info_DM_RES_DWN         PIN_DM_RES_DWN
        #define Pin_LED_info_DM_OD_LO           PIN_DM_OD_LO
        #define Pin_LED_info_DM_OD_HI           PIN_DM_OD_HI
        #define Pin_LED_info_DM_STRONG          PIN_DM_STRONG
        #define Pin_LED_info_DM_RES_UPDWN       PIN_DM_RES_UPDWN
    /** @} driveMode */
/** @} group_constants */
    
/* Digital Port Constants */
#define Pin_LED_info_MASK               Pin_LED_info__MASK
#define Pin_LED_info_SHIFT              Pin_LED_info__SHIFT
#define Pin_LED_info_WIDTH              1u

/* Interrupt constants */
#if defined(Pin_LED_info__INTSTAT)
/**
* \addtogroup group_constants
* @{
*/
    /** \addtogroup intrMode Interrupt constants
     * \brief Constants to be passed as "mode" parameter in Pin_LED_info_SetInterruptMode() function.
     *  @{
     */
        #define Pin_LED_info_INTR_NONE      (uint16)(0x0000u)
        #define Pin_LED_info_INTR_RISING    (uint16)(0x0001u)
        #define Pin_LED_info_INTR_FALLING   (uint16)(0x0002u)
        #define Pin_LED_info_INTR_BOTH      (uint16)(0x0003u) 
    /** @} intrMode */
/** @} group_constants */

    #define Pin_LED_info_INTR_MASK      (0x01u) 
#endif /* (Pin_LED_info__INTSTAT) */


/***************************************
*             Registers        
***************************************/
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

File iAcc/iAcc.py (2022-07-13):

from setuptools import find_packages
import variables as var
from re import L
import struct
import sys
from telnetlib import STATUS
import time
import logging
import matplotlib.pyplot as plt
import numpy as np
from scipy.signal import find_peaks
import scipy.signal as signal
from scipy.signal import butter

from PyQt5.QtWidgets import * 
from PyQt5 import QtCore, QtGui
from PyQt5.QtGui import * 
from PyQt5.QtCore import *

# We import library dedicated to data plot
import pyqtgraph as pg
from pyqtgraph import PlotWidget

import serial 
import serial.tools.list_ports

import pandas as pd

#Logging config
logging.basicConfig(format="%(message)s", level=logging.INFO)

#########################
# SERIAL_WORKER_SIGNALS #
#########################
class SerialWorkerSignals(QObject):
    """!
    @brief Class that defines the signals available to a serialworker.

    Available signals (with respective inputs) are:
        - device_port:
            str --> port name to which a device is connected
        - status:
            str --> port name
            int --> macro representing the state (0 - error during opening, 1 - success)
    """
    device_port = pyqtSignal(str)
    status = pyqtSignal(str, int)

#################
# SERIAL_WORKER #
#################
class SerialWorker(QRunnable):
    """!
    @brief Main class for serial communication: handles connection with device.
    """
    def __init__(self, serial_port_name):
        """!
        @brief Init worker.
        """
        self.is_killed = False
        super().__init__()
        #init port, params and signals
        self.port = serial.Serial()
        self.port_name = serial_port_name
        self.baudrate = var.baudRate #hard coded but can be a global variable, or an input param
        self.signals = SerialWorkerSignals()

    @pyqtSlot()
    def run(self):
        """!
        @brief Estabilish connection with desired serial port.
        """

        if not var.CONN_STATUS:
            try:
                self.port = serial.Serial(port=self.port_name, baudrate=self.baudrate,
                                        write_timeout=0, timeout=2)                
                if self.port.is_open:
                    self.send('t')
                    time.sleep(1)

                    if(self.read()=="HR/RR sensor"):
                        var.CONN_STATUS = True
                        self.signals.status.emit(self.port_name, 1)
                        time.sleep(1) #just for compatibility reasons 
                    var.connectionWait = False   
                           
            except serial.SerialException:
                logging.info("Error with port {}.".format(self.port_name))
                self.signals.status.emit(self.port_name, 0)
                time.sleep(0.01)
                var.connectionWait=False

    @pyqtSlot()
    def send(self, char):
        """!
        @brief Basic function to send a single char on serial port.
        """
        try:
            self.port.write(char.encode('utf-8'))
            logging.info("Written {} on port {}.".format(char, self.port_name))
        except:
            logging.info("Could not write {} on port {}.".format(char, self.port_name))

    @pyqtSlot()
    def read(self):
        """!
        @brief Basic function to read a single char on serial port.
        """
        testString=''
        try:
            while(self.port.in_waiting>0):
                testString+=self.port.read().decode('utf-8', errors='replace')
                #logging.info(self.port.in_waiting)
            logging.info("Received: {}".format(testString))
            return testString
        except:
            logging.info("Could not receive {} on port {}.".format(testString, self.port_name))
   
    @pyqtSlot()
    def readAcc(self):
        """!
        @brief Basic function to read a single char on serial port.
        """
        testString=''
        try:
            while(self.port.in_waiting>0):
                testString+=self.port.read().decode('utf-8', errors='replace')
                #logging.info(self.port.in_waiting)
            #logging.info("Received: {}".format(testString))
            return testString
        except:
            logging.info("Could not receive {} on port {}.".format(testString, self.port_name))

    @pyqtSlot()
    def killed(self):
        """!
        @brief Close the serial port before closing the app.
        """

        if self.is_killed and var.CONN_STATUS:
            self.send('s')
            self.port.close()
            time.sleep(0.01)
            var.CONN_STATUS = False
            self.signals.device_port.emit(self.port_name)
            
        logging.info("Killing the process")

    @pyqtSlot()
    def readData(self):
        """!
        @brief Function used to read the data and to implement the HR and RR algorithms. 
               Moreover we implemented a warning signal for the user in case of losing the connection. 
        """

        try:
            dataArray = self.port.read(194)
            dataArray = struct.unpack('194B',dataArray)
            dataArray = np.asarray(dataArray,dtype=np.uint8)
            lastIndex = len(dataArray)-1
            if(dataArray[0]==10 and dataArray[lastIndex]==11):
                accData = dataArray[1:193]
                for i in range(var.axisSize):
                
                    var.xData[i] =  (((accData[i*6+1] & 0xFF)<<8) | (accData[i*6] & 0xFF))>>6
                    var.yData[i] =  (((accData[i*6+3] & 0xFF)<<8) | (accData[i*6+2] & 0xFF))>>6
                    var.zData[i] =  (((accData[i*6+5] & 0xFF)<<8) | (accData[i*6+4] & 0xFF))>>6

                    if(var.xData[i]>511 & var.xData[i]<1024):
                        var.xData_g[i] = var.xData[i]*(var.mDigitNeg)+var.qDigitNeg
                    else:
                        var.xData_g[i] = var.xData[i]*(var.mdigitPos) - var.qDigitPos
                    if(var.yData[i]>511 & var.yData[i]<1024):
                        var.yData_g[i] = var.yData[i]*(var.mDigitNeg)+var.qDigitNeg
                    else:
                        var.yData_g[i] = var.yData[i]*(var.mdigitPos) - var.qDigitPos
                    if(var.zData[i]>511 & var.zData[i]<1024):
                        var.zData_g[i] = var.zData[i]*(var.mDigitNeg)+var.qDigitNeg
                    else:
                        var.zData_g[i] = var.zData[i]*(var.mdigitPos) - var.qDigitPos
                  
                    # Sum_data is used to calculate the HR rate in order to be more robust against movements
                    var.sum_data[i]=var.zData_g[i]+var.yData_g[i]      
            
            # In order to plot a real time graph which is filtered
            var.zData_lowpass = self.butter_lowpass_filter(var.zData_g, var.cutoff_RR, var.SAMPLE_RATE, var.order)
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

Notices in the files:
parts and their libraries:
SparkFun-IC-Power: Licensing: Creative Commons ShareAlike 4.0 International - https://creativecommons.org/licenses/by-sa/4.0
